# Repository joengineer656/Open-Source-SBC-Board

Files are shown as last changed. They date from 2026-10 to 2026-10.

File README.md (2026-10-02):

# Open-Source-SBC-Board

A custom single-board computer built around the Rockchip RK3576 SoC, designed as a learning project to explore modern SBC architecture.

> **Status: Work in Progress — v2 current.** Schematic in progress. Not yet fabricated. V2 schematics are not final – expect minor errors.

## Which version are you looking at?

**You are viewing `v2` (default, `main` branch).**

- **Want v1 (old)?** 
  - Switch branch: `archive/v1` in the GitHub branch dropdown, or
  - Download ZIP: [Releases → v1.0](https://github.com/joengineer656/Open-Source-SBC-Board/releases/tag/v1.0)
  - Clone specific: `git clone -b archive/v1 https://github.com/joengineer656/Open-Source-SBC-Board.git`
- **Want v2?** You're here. Or [Releases → v2.0](https://github.com/joengineer656/Open-Source-SBC-Board/releases/tag/v2.0) for ZIP.

| Version | Branch | Tag | Status |
|---|---|-----|---|
| v2 (this page) | `main` | `v2.0` | active development, default view |
| v1 (archived) | `archive/v1` | `v1.0` | frozen, read-only |

## Overview

This board is a learning project exploring the design of a modern, feature-rich SBC. It combines a high-performance RK3576 application processor with an RP2350A companion MCU for IO offloading, targeting a balance between compute power and real-time IO capability.

V2 is a cleaned-up / upgraded version of the V1 design (ref: [devmeb0/RK3576-SBC](https://github.com/devmeb0/RK3576-SBC)). Main V2 deltas: **second Gigabit Ethernet port, M.2 Key-E socket for wireless modules (no FCC cert needed for the base board), onboard CR2032 RTC backup battery (not external), schematic cleanup + notes throughout.**

## Key Specifications (v2)

| Feature | Specification |
|---|---|
| **SoC** | Rockchip RK3576 – 4x Cortex-A72 @ 2.2GHz + 4x Cortex-A53 @ 1.8GHz, Mali-G52 MC3, 6 TOPS NPU |
| **Companion MCU** | Raspberry Pi RP2350A (IO co-processor, USB-C, SWD/JTAG) |
| **RAM** | 32-bit LPDDR5 (Micron MT62F1G32D4DR-031) |
| **Storage** | UFS 2.0, eMMC 5.1 modular, µSD card, SPI flash (W25Q128 for MCU) |
| **Video Output** | HDMI 2.1 / eDP 1.3, USB-C DP1.4 Alt-Mode, 4-lane MIPI DSI + 0.96" OLED header |
| **Camera** | MIPI CSI 4-lane (or split 2+2) |
| **Networking** | Dual Gigabit Ethernet (2x RTL8211F, PoE optional), M.2 Key-E 67-pin for WiFi/BT |
| **USB** | 4x USB 3.2 Host (RTS5411 hub), 1x USB-C OTG/PD (FUSB302), 1x USB-C for MCU |
| **Expansion** | 40-pin RPi-compatible header, PCIe 2.1 x1 + SATA3 via FPC |
| **Display** | 0.96" OLED header (8-pin) |
| **RTC** | RV-3028-C7 + FRAM, onboard CR2032 holder (BAT-HLD-001) |
| **PMIC** | RK806S-5 + SY8388 / SY8089 DC/DCs |
| **Power In** | Barrel jack, USB-C 5V, USB-C PD, PoE option, 40-pin header |

## Features (v2)

**1. SoC – Rockchip RK3576 (FCCSP698)**
Octa-core big.LITTLE, Cortex-M0 for user code, Mali-G52 MC3 (OpenGL ES 3.2 / Vulkan 1.2 / OpenCL 2.1), 6 TOPS NPU (INT4/8/16, FP16/BF16/TF32), 16MP ISP with HDR/3DNR, 8K@30 / 4K@120 decode, 4K@60 encode. 2x RGMII, PCIe2.1/SATA3/USB3 combo lanes, 2x CAN-FD on-chip. OS: Linux / Android 14 / Yocto / Buildroot.

**2. Memory – 32-bit LPDDR5**
`LPDDR5.kicad_sch`: Micron MT62F1G32D4DR-031, 32-bit dual-channel layout per RK3576 reference.

**3. Storage – eMMC + UFS + microSD + SPI**
- `eMMC/UFS.kicad_sch` + `UFS/eMMC.kicad_sch`: eMMC 5.1 modular footprint + UFS 2.0 HS-G3.
- `uSD_Card.kicad_sch`: push-push microSD with AP2553 load-switch power + TPD4E ESD.
- `RP2350A.kicad_sch`: 2x W25Q128JVS SPI flash for the co-MCU.

**4. Display – 3x concurrent**
- `HDMI.kicad_sch`: HDMI 2.1 / eDP 1.3 combo, TPD4E05U06 ESD, TXB0104 translators, AP2553 5V switch.
- `USBC_SOC.kicad_sch`: USB-C Alt-Mode DP1.4 + USB3 combo, FUSB302 PD controller, TPS22953 switches.
- `MIPI.kicad_sch`: 4-lane MIPI DSI TX via 30-pin FPC, TXS0108 level-shifted.
- `oled_screen.kicad_sch`: 0.96" OLED 8-pin header for status/debug.

**5. Network – Dual GbE + M.2 Key-E (V2 highlight)**
- `Ethernet.kicad_sch`: 2x RTL8211F-CG PHYs (U25/U26, 2x 25 MHz crystals), LPJG0926HENL magjacks, PoE input headers (PoE optional).
- `Wireless.kicad_sch`: M.2 Key-E 67-pin socket APCI0108-P001A (LCSC C7498141), 0.5 mm right-angle, for off-the-shelf WiFi/BT modules – replaces soldered wireless, so the base board itself needs no FCC certification.

**6. USB**
- `USBA_Host.kicad_sch`: 4x USB3.2 Host via 2x RTS5411S-GR hubs, SY6280 current-limit per port, TPD4E ESD.
- `USBC_SOC.kicad_sch`: 1x USB-C OTG/Host Alt-Mode with PD negotiation – can also be power input.
- `RP2350A.kicad_sch`: separate USB-C 2.0 16P for the MCU.

**7. Camera**
`MIPI.kicad_sch`: MIPI CSI RX – 4-lane or split 2+2. Feeds RK3576 triple CSI + 16MP ISP.

**8. Power – RK806S-5 + discretes**
`Power.kicad_sch`: RK806S-5 PMIC, 2x SY8388ARHC + SY8089AAAC DC/DCs, AO3401 FETs, SMBJ TVS. Inputs: barrel-jack, USB-C 5V/3A-5A with UVLO/OVLO, USB-C PD in, PoE option, or 40-pin header 5V.

**9. RTC – onboard battery (V2 change)**
`RTC.kicad_sch`: RV-3028-C7 RTC + FM24C64/M24C64 FRAM/EEPROM, AO3401 OR-ing, fuse + SMBJ. CR2032 coin holder Linx BAT-HLD-001 **on-board** – V1 used an external JST battery.

**10. Expansion**
- `PCIe.kicad_sch` + `connectors.kicad_sch`: PCIe 2.1 x1 + SATA3 via TE 1-2199230-5 FPCs.
- `40pin_GPIO.kicad_sch`: Raspberry-Pi-compatible 40-pin header, 3x AP2553 load switches, SMBJ ESD: 28x GPIO / 13x PWM, 5x UART, 5x I2C, 1x I3C, 2x SPI, CAN, PDM, SDIO, 12-bit SAR-ADC 1MS/s, 3.3V out / 5V in-out.

**11. Co-MCU – RP2350A**
`RP2350A.kicad_sch`: RP2350A with ETA7014 regulators, W25Q128 flash, USB-C, SWD/JTAG header, tactile buttons. For real-time IO / housekeeping offload.

**12. Bring-up / mechanical**
`Fixtures.kicad_sch`: mounting holes, fiducials, test-point probes, UART/SWD debug header, boot DIP, maskrom + power tactiles, dual power/activity LEDs, active fan header.

## Architecture

```
┌─────────────────────────────────────────────────────┐
│                    RK3576 SoC                        │
│  ┌──────────┐  ┌──────────┐  ┌──────────────────┐  │
│  │  CPU     │  │  GPU     │  │  Memory Ctrl     │  │
│  │  (ARM)   │  │          │  │  (LPDDR5)        │  │
│  └──────────┘  ──────────┘  └──────────────────  │
│  ┌──────────  ┌──────────┐  ┌──────────────────┐  │
│  │  PCIe    │  │  USB 3.2 │  │  MIPI CSI/DSI    │  │
│  └──────────  └──────────┘  └──────────────────┘  │
│  ┌──────────┐  ┌──────────┐  ┌──────────────────┐  │
│  │  HDMI    │  │  Ethernet│  │  UFS/eMMC/SD     │  │
│  └──────────┘  └──────────┘  └──────────────────┘  │
└─────────────────────────────────────────────────────┘
         │                    │
         │ SPI/I2C/UART       │ USB
         ▼                    ▼
─────────────────┐   ┌─────────────────┐
│   RP2350A MCU   │   │   USB Hub       │
│  (IO offload)   │   │  (Host ports)   │
└─────────────────┘   └─────────────────┘
         │
         ▼
┌─────────────────┐
│  40-pin Header  │
│  (RPi compat)   │
└─────────────────┘
```

## Open in KiCad

Project file: `RK3576 SBCv2.kicad_pro` (KiCad 10.0)
Top sheet: `block_diagrame.kicad_sch` → `RK3576.kicad_sch` (SOC) + peripherals.

## Schematic Sheets (v2)

| Sheet | Description |
|---|---|
| `block_diagrame.kicad_sch` | Top-level block diagram |
| `RK3576.kicad_sch` | RK3576 SoC, decoupling, strapping |
| `RP2350A.kicad_sch` | RP2350A companion MCU, USB-C, SWD |
| `Power.kicad_sch` | RK806S-5 PMIC and power distribution |
| `LPDDR5.kicad_sch` | LPDDR5 memory (Micron MT62F) |
| `Ethernet.kicad_sch` | Dual Gigabit Ethernet (2x RTL8211F, PoE) |
| `Wireless.kicad_sch` | M.2 Key-E 67-pin WiFi/BT socket |
| `HDMI.kicad_sch` | HDMI 2.1 output |
| `MIPI.kicad_sch` | MIPI DSI/CSI via FPC |
| `PCIe.kicad_sch` | PCIe 2.1 / SATA via FPC |
| `USBA_Host.kicad_sch` | 4x USB-A host (RTS5411 hub) |
| `USBC_SOC.kicad_sch` | USB-C to SoC, PD (FUSB302) |
| `uSD_Card.kicad_sch` | µSD card slot |
| `eMMC/UFS.kicad_sch` + `UFS/eMMC.kicad_sch` | eMMC / UFS storage |
| `RTC.kicad_sch` | RV-3028 RTC + onboard CR2032 |
| `oled_screen.kicad_sch` | 0.96" OLED header |
| `40pin_GPIO.kicad_sch` | RPi-compatible header |
| `connectors.kicad_sch`, `dc_power_soket.kicad_sch` | Power / debug connectors |
| `Fixtures.kicad_sch` | Test points, fiducials |
| `directive_labels.kicad_sch` | Netclass directives |

> Note: `eMMC/UFS.kicad_sch` and `UFS/eMMC.kicad_sch` names are swapped upstream — kept as-is to avoid breaking sheet references. Excluded from repo (per `.gitignore`): `.history/`, `Resources/`, `*.bak`, `*.lck`, `project.kicad_dru`, `.hs_rules.json`, lowercase dup placeholders (`fixtures`/`power`), empty orphans (`digital`, `mechanical`, `output`, `USBC_MCU`, `eMMC_UFS`).

## Repository Structure (v2 on `main`)

```
Open-Source-SBC-Board/ (main = v2)
├── RK3576 SBCv2.kicad_pro       # KiCad project file
├── RK3576 SBCv2.kicad_sch       # Project root sheet
├── RK3576 SBCv2.kicad_pcb       # PCB layout (in progress)
├── RK3576 SBCv2.kicad_prl
├── RK3576 SBCv2.kicad_dru
├── *.kicad_sch                  # Hierarchical schematic sheets
├── eMMC/ UFS/                   # Storage sheets
├── LICENSE                      # CERN-OHL-P v2
├── README.md                     # This file
└── .gitignore                    # KiCad ignores (*.bak, .lck, .history/)
```

v1 lives only on branch `archive/v1` + tag `v1.0`, not in this tree.

## Design Goals

1. **Learn modern SBC design** — power delivery, high-speed interfaces (LPDDR5, UFS, PCIe, USB 3.2), mixed-signal layout
2. **Real-time IO capability** — RP2350A handles time-critical tasks independently of the Linux-running SoC
3. **Rich connectivity** — Dual Ethernet, M.2 Key-E WiFi/BT, USB, PCIe, MIPI, HDMI in a compact form factor
4. **Open source** — full schematic and PCB released under CERN-OHL-P

## For maintainers: how versions are stored

```bash
# v1 frozen
git branch archive/v1   # from old main
git tag v1.0 archive/v1

# v2 is main
git tag v2.0 main

# push all (needs auth)
git push origin archive/v1 v1.0 main v2.0
gh release create v1.0 --target archive/v1 --title "v1.0 - archived" --notes "Frozen v1. See branch archive/v1."
gh release create v2.0 --target main --title "v2.0 - current" --notes "Current v2. Default branch main."
```

Users get v2 by default, v1 via branch dropdown or Releases ZIP — i.e. “2 repos in 1 repo”.

## License

This hardware design is licensed under the **CERN Open Hardware Licence Version 2 — Permissive** (CERN-OHL-P v2).

See [LICENSE](LICENSE) for the full text.

## Acknowledgments

- [Rockchip](https://www.rock-chips.com/) for the RK3576 SoC
- [Raspberry Pi](https://www.raspberrypi.com/) for the RP2350A
- [KiCad](https://www.kicad.org/) for the EDA tools
- [CERN](https://ohwr.org/project/cernohl/) for the OHL license
- [devmeb0/RK3576-SBC](https://github.com/devmeb0/RK3576-SBC) V1 reference design

---

*This is a learning project. The design has not been fabricated or tested yet. Use at your own risk.*

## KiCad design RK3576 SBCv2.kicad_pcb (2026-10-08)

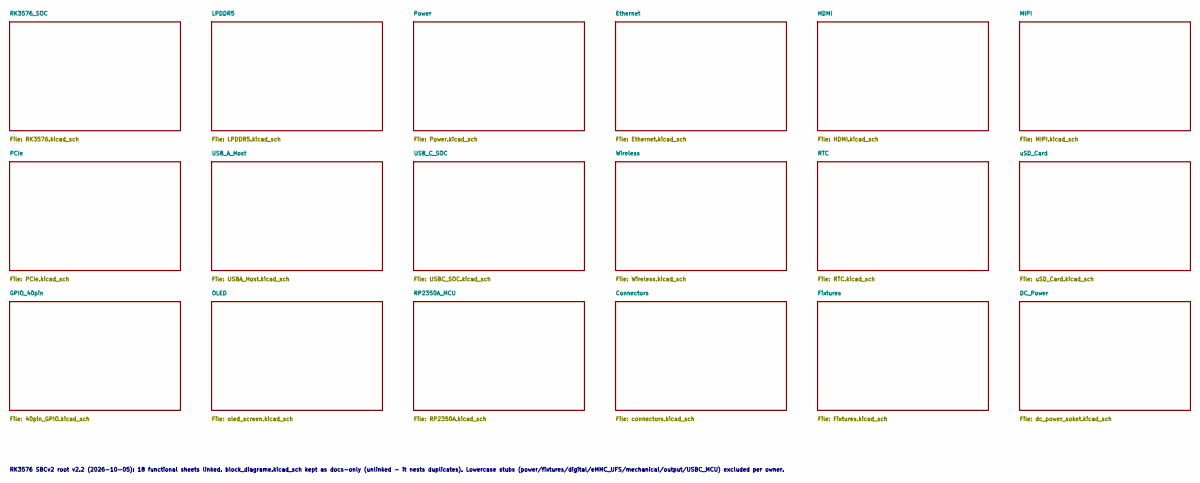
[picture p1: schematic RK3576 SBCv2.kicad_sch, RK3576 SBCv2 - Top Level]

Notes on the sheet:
RK3576 SBCv2 root v2.2 (2026-10-05): 18 functional sheets linked. block_diagrame.kicad_sch kept as docs-only (unlinked - it nests duplicates). Lowercase stubs (power/fixtures/digital/eMMC_UFS/mechanical/output/USBC_MCU) excluded per owner.

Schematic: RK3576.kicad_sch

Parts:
C1, C10: 12pF; C_0402_1005Metric; Mouser Part 187-CL05C120JB5NNNC; LCSC Part C26406
C2, C3, C4, C5, C6, C48, C49, C50, C106, C107, C108, C109, C110, C111: 22u; C_0603_1608Metric; Mouser Part CL10A226MP8NUNE; LCSC Part C86295
C7, C8, C9, C11, C13, C14, C15, C16, C18, C19, C20, C21, C22, C23, C28, C35, C36, C37, C38, C39, C40, C42, C47, C51, C53, C54, C55, C56, C57, C59, C60, C61, C62, C63, C64, C65, C66, C67, C68, C69, C70, C71, C72, C73, C74, C75, C76, C77, C78, C79, C80, C81, C82, C83, C84, C85, C86, C87, C88, C89, C90, C91, C92, C93, C94, C95, C96, C97, C98, C99, C100, C101, C102, C103, C104: 1u; C_0201_0603Metric_Pad0.64x0.40mm_HandSolder; Mouser Part CL03A105KP3NSNC; LCSC Part C5209398
C12, C17, C41, C43, C44, C45, C46, C52, C58: 10u; C_0603_1608Metric; Mouser Part 187-CL10A106KP8NNNC; LCSC Part C19702
C24, C25, C26, C27, C29, C30, C31, C32, C33, C34: 100n; C_0201_0603Metric_Pad0.64x0.40mm_HandSolder; Mouser Part 187-CL03A104KO3NNND; LCSC Part C307380
C105, C112: 18pF; C_0402_1005Metric; Mouser Part 603-CC402FRNPO9BN180; LCSC Part C541431
D1, D2: PESD5V0S1BA; D_SOD-323_TVS; Mouser Part 771-PESD5V0S1BA-T/R; LCSC Part C5158048
D3: SMBJ5.0CA; D_SMB_TVS; Mouser Part 581-SMBJ5.0CA; LCSC Part C113975
J1: B4B Connector; FanPinHeader_1x04_P2.54mm_Vertical; Mouser Part 306-B4BXHALFSN; LCSC Part C144395
LED1, LED2: XL-1608SURC-06; LED_0603_1608Metric; LCSC Part C965799
Q1: 2SK3018; SOT-323_SC-70; LCSC Part C20069148
R1: 4.7k; R_0402_1005Metric; Mouser Part 603-RC0402FR-074K7L; LCSC Part C105871; not fitted
R2, R30, R31, R32, R34: 22R; R_0402_1005Metric; Mouser Part 603-RC0402FR-070RL; LCSC Part C106231
R3, R5, R6, R26, R28: 4.7k; R_0402_1005Metric; Mouser Part 603-RC0402FR-074K7L; LCSC Part C105871
R4, R33: 510k; R_0402_1005Metric; Mouser Part 603-RC0402FR-07510KL; LCSC Part C137961
R7, R233: 0R; R_0402_1005Metric; Mouser Part 603-RC0402FR-070RL; LCSC Part C106231
R8, R9: 100R; R_0402_1005Metric; Mouser Part 603-RC0402FR-0722RL; LCSC Part C114765
R10, R18, R19, R20, R21, R22, R23: 10k; R_0402_1005Metric; Mouser Part 603-RC0402FR-0710KL; LCSC Part C60490
R11, R13, R14: 1k; R_0402_1005Metric; Mouser Part 603-RC0402FR-071KL; LCSC Part C106235
R12: 100k; R_0402_1005Metric; Mouser Part 603-RC0402FR-0710KL; LCSC Part C60490
R15: 6.8k; R_0402_1005Metric; Mouser Part 603-RC0402FR-076K8L; LCSC Part C93940
R16: 23.2k; R_0402_1005Metric; Mouser Part 603-AC0402FR-0723K2L; LCSC Part C226362
R17: 88.7k; R_0402_1005Metric; Mouser Part 603-RC0402FR-0788K7L; LCSC Part C477808
R24, R25, R35: 8.2k; R_0402_1005Metric; Mouser Part 603-RT0402FRE078K2L; LCSC Part C136971
R27, R29: 200R; R_0402_1005Metric; Mouser Part 603-RT0402FRE07200RL; LCSC Part C854192
SW1: DSHP03TS-S; SW_DIP_SPSTx03_Slide_KingTek_DSHP03TJ_W5.25mm_P1.27mm_JPin; LCSC Part C319051
SW2: XUNPU TS-1089S-02526; LCSC Part C455282
U1: RK3576; FCCSP-698_L17.2-W16.1-TL_RK3576; MPN RK3576; LCSC Part C42388007
Y1: TXM24M0004322FBCDO00T; Crystal_SMD_3225-4Pin_3.2x2.5mm; LCSC Part C362340
Y2: XTM32026000FT00351001; Crystal_SMD_3225-4Pin_3.2x2.5mm; LCSC Part C37635380

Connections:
/40pin GPIO/I2C8_SCL_M3_RTC_EEPROM: U1.A11 (I2C8_SCL_M3); also elsewhere on the board
/40pin GPIO/I2C8_SDA_M3_RTC_EEPROM: U1.A13 (I2C8_SDA_M3); also elsewhere on the board
/40pin GPIO/SPI1_{MCU}.CS: R6.2, U1.1E7 (GPIO3_D7_d); also elsewhere on the board
/40pin GPIO/SPI1_{MCU}.SCK: R1.2, U1.1E12 (SPI3_CLK_M1); also elsewhere on the board
/40pin GPIO/SPI1_{MCU}.SDI: R5.2, U1.1C10 (SPI3_MOSI_M1); also elsewhere on the board
/40pin GPIO/SPI1_{MCU}.SDO: R3.2, U1.1D10 (SPI3_MISO_M1); also elsewhere on the board
/Ethernet/ETH0_{PHY}.MDC: U1.1B13 (ETH1_MDC_M0); also elsewhere on the board
/Ethernet/ETH0_{PHY}.MDIO: U1.1B15 (ETH1_MDIO_M0); also elsewhere on the board
/Ethernet/ETH0_{PHY}.RXC: U1.1C18 (ETH0_RXCLK_M1); also elsewhere on the board
/Ethernet/ETH0_{PHY}.RXCTL: U1.1A20 (ETH0_RXCTL_M1); also elsewhere on the board
/Ethernet/ETH0_{PHY}.RXD0: U1.B22 (ETH0_RXD0_M1); also elsewhere on the board
/Ethernet/ETH0_{PHY}.RXD1: U1.1A19 (ETH0_RXD1_M1); also elsewhere on the board
/Ethernet/ETH0_{PHY}.RXD2: U1.B21 (ETH0_RXD2_M1); also elsewhere on the board
/Ethernet/ETH0_{PHY}.RXD3: U1.A21 (ETH0_RXD3_M1); also elsewhere on the board
/Ethernet/ETH0_{PHY}.TXC: U1.1B16 (ETH0_TXCLK_M1); also elsewhere on the board
/Ethernet/ETH0_{PHY}.TXCTL: U1.B20 (ETH0_TXCTL_M1); also elsewhere on the board
/Ethernet/ETH0_{PHY}.TXD0: U1.1A18 (ETH0_TXD0_M1); also elsewhere on the board
/Ethernet/ETH0_{PHY}.TXD1: U1.B19 (ETH0_TXD1_M1); also elsewhere on the board
/Ethernet/ETH0_{PHY}.TXD2: U1.A19 (ETH0_TXD2_M1); also elsewhere on the board
/Ethernet/ETH0_{PHY}.TXD3: U1.1A17 (ETH0_TXD3_M1); also elsewhere on the board
/Ethernet/ETH0_{PHY}_CLK_{OUT}: U1.1E15 (ETH_CLK0_25M_OUT_M1); also elsewhere on the board
/Ethernet/ETH0_{PHY}_INT: U1.1C6 (GPIO4_A3_d); also elsewhere on the board
/Ethernet/ETH0_{PHY}_nRST: U1.1D6 (GPIO4_A2_d); also elsewhere on the board
/Ethernet/ETH1_{PHY}.MDC: U1.1B18 (ETH0_MDC_M1); also elsewhere on the board
/Ethernet/ETH1_{PHY}.MDIO: U1.1D16 (ETH0_MDIO_M1); also elsewhere on the board
/Ethernet/ETH1_{PHY}.RXC: U1.1D15 (ETH1_RXCLK_M0); also elsewhere on the board
/Ethernet/ETH1_{PHY}.RXCTL: U1.B18 (ETH1_RXCTL_M0); also elsewhere on the board
/Ethernet/ETH1_{PHY}.RXD0: U1.1A16 (ETH1_RXD0_M0); also elsewhere on the board
/Ethernet/ETH1_{PHY}.RXD1: U1.B17 (ETH1_RXD1_M0); also elsewhere on the board
/Ethernet/ETH1_{PHY}.RXD2: U1.A17 (ETH1_RXD2_M0); also elsewhere on the board
/Ethernet/ETH1_{PHY}.RXD3: U1.1A15 (ETH1_RXD3_M0); also elsewhere on the board
/Ethernet/ETH1_{PHY}.TXC: U1.1C15 (ETH1_TXCLK_M0); also elsewhere on the board
/Ethernet/ETH1_{PHY}.TXCTL: U1.B16 (ETH1_TXCTL_M0); also elsewhere on the board
/Ethernet/ETH1_{PHY}.TXD0: U1.1A14 (ETH1_TXD0_M0); also elsewhere on the board
/Ethernet/ETH1_{PHY}.TXD1: U1.B15 (ETH1_TXD1_M0); also elsewhere on the board
/Ethernet/ETH1_{PHY}.TXD2: U1.A15 (ETH1_TXD2_M0); also elsewhere on the board
/Ethernet/ETH1_{PHY}.TXD3: U1.1A13 (ETH1_TXD3_M0); also elsewhere on the board
/Ethernet/ETH1_{PHY}_CLK_{OUT}: U1.1D18 (ETH_CLK1_25M_OUT_M0); also elsewhere on the board
/Ethernet/ETH1_{PHY}_INT: U1.1B6 (GPIO4_A5_d); also elsewhere on the board
/Ethernet/ETH1_{PHY}_nRST: U1.1C5 (GPIO4_A4_d); also elsewhere on the board
/HDMI/HDMI_PWREN_H: U1.AK1 (GPIO4_C5_d); also elsewhere on the board
/HDMI/HDMI_TX_CEC_M0: U1.AK3 (HDMI_TX_CEC_M0); also elsewhere on the board
/HDMI/HDMI_TX_HPDIN_M0: U1.AK2 (HDMI_TX_HPDIN_M0); also elsewhere on the board
/HDMI/HDMI_TX_ON: U1.AL3 (GPIO4_C4_d); also elsewhere on the board
/HDMI/HDMI_TX_SCL: U1.AL2 (HDMI_TX_SCL); also elsewhere on the board
/HDMI/HDMI_TX_SDA: U1.1AE2 (HDMI_TX_SDA); also elsewhere on the board
/LPDDR5/LPDDR5_A.CA0: U1.T1 (LP5_A0_A); also elsewhere on the board
/LPDDR5/LPDDR5_A.CA1: U1.1N1 (LP5_A1_A); also elsewhere on the board
/LPDDR5/LPDDR5_A.CA2: U1.1R3 (LP5_A2_A); also elsewhere on the board
/LPDDR5/LPDDR5_A.CA3: U1.1T2 (LP5_A3_A); also elsewhere on the board
/LPDDR5/LPDDR5_A.CA4: U1.1M5 (LP5_A4_A); also elsewhere on the board
/LPDDR5/LPDDR5_A.CA5: U1.1P5 (LP5_A5_A); also elsewhere on the board
/LPDDR5/LPDDR5_A.CA6: U1.1R5 (LP5_A6_A); also elsewhere on the board
/LPDDR5/LPDDR5_A.CK_N: U1.P1 (LP5_CLKN_A); also elsewhere on the board
/LPDDR5/LPDDR5_A.CK_P: U1.1L1 (LP5_CLKP_A); also elsewhere on the board
/LPDDR5/LPDDR5_A.CS0: U1.1N3 (LP5_CSN0_A); also elsewhere on the board
/LPDDR5/LPDDR5_A.CS1: U1.1N5 (LP5_CSN1_A); also elsewhere on the board
/LPDDR5/LPDDR5_A.DMI0: U1.1V1 (LP5_DMI0_A); also elsewhere on the board
/LPDDR5/LPDDR5_A.DMI1: U1.AE1 (LP5_DMI1_A); also elsewhere on the board
/LPDDR5/LPDDR5_A.DQ0: U1.W1 (LP5_DQ0_A); also elsewhere on the board
/LPDDR5/LPDDR5_A.DQ1: U1.1T1 (LP5_DQ1_A); also elsewhere on the board
/LPDDR5/LPDDR5_A.DQ2: U1.1P1 (LP5_DQ2_A); also elsewhere on the board
/LPDDR5/LPDDR5_A.DQ3: U1.U1 (LP5_DQ3_A); also elsewhere on the board
/LPDDR5/LPDDR5_A.DQ4: U1.1V3 (LP5_DQ4_A); also elsewhere on the board
/LPDDR5/LPDDR5_A.DQ5: U1.1W4 (LP5_DQ5_A); also elsewhere on the board
/LPDDR5/LPDDR5_A.DQ6: U1.AC1 (LP5_DQ6_A); also elsewhere on the board
/LPDDR5/LPDDR5_A.DQ7: U1.AB1 (LP5_DQ7_A); also elsewhere on the board
/LPDDR5/LPDDR5_A.DQ8: U1.AF1 (LP5_DQ8_A); also elsewhere on the board
/LPDDR5/LPDDR5_A.DQ9: U1.1AB1 (LP5_DQ9_A); also elsewhere on the board
/LPDDR5/LPDDR5_A.DQ10: U1.1AD1 (LP5_DQ10_A); also elsewhere on the board
/LPDDR5/LPDDR5_A.DQ11: U1.AH1 (LP5_DQ11_A); also elsewhere on the board
/LPDDR5/LPDDR5_A.DQ12: U1.1Y1 (LP5_DQ12_A); also elsewhere on the board
/LPDDR5/LPDDR5_A.DQ13: U1.1W2 (LP5_DQ13_A); also elsewhere on the board
/LPDDR5/LPDDR5_A.DQ14: U1.1AA3 (LP5_DQ14_A); also elsewhere on the board
/LPDDR5/LPDDR5_A.DQ15: U1.1AA1 (LP5_DQ15_A); also elsewhere on the board
/LPDDR5/LPDDR5_A.RDQS0_N: U1.Y1 (LP5_RDQS0N_A); also elsewhere on the board
/LPDDR5/LPDDR5_A.RDQS0_P: U1.1U1 (LP5_RDQS0P_A); also elsewhere on the board
/LPDDR5/LPDDR5_A.RDQS1_N: U1.1AB3 (LP5_RDQS1N_A); also elsewhere on the board
/LPDDR5/LPDDR5_A.RDQS1_P: U1.1AB4 (LP5_RDQS1P_A); also elsewhere on the board
/LPDDR5/LPDDR5_A.WCK0_N: U1.1V4 (LP5_WCK0N_A); also elsewhere on the board
/LPDDR5/LPDDR5_A.WCK0_P: U1.1V5 (LP5_WCK0P_A); also elsewhere on the board
/LPDDR5/LPDDR5_A.WCK1_N: U1.1AA5 (LP5_WCK1N_A); also elsewhere on the board
/LPDDR5/LPDDR5_A.WCK1_P: U1.1AA6 (LP5_WCK1P_A); also elsewhere on the board
/LPDDR5/LPDDR5_B.CA0: U1.L1 (LP5_A0_B); also elsewhere on the board
/LPDDR5/LPDDR5_B.CA1: U1.1J1 (LP5_A1_B); also elsewhere on the board
/LPDDR5/LPDDR5_B.CA2: U1.1J3 (LP5_A2_B); also elsewhere on the board
/LPDDR5/LPDDR5_B.CA3: U1.1G2 (LP5_A3_B); also elsewhere on the board
/LPDDR5/LPDDR5_B.CA4: U1.1F4 (LP5_A4_B); also elsewhere on the board
/LPDDR5/LPDDR5_B.CA5: U1.1K5 (LP5_A5_B); also elsewhere on the board
/LPDDR5/LPDDR5_B.CA6: U1.1H5 (LP5_A6_B); also elsewhere on the board
/LPDDR5/LPDDR5_B.CK_N: U1.N1 (LP5_CLKN_B); also elsewhere on the board
/LPDDR5/LPDDR5_B.CK_P: U1.1K1 (LP5_CLKP_B); also elsewhere on the board
/LPDDR5/LPDDR5_B.CS0: U1.1K2 (LP5_CSN0_B); also elsewhere on the board
/LPDDR5/LPDDR5_B.CS1: U1.1M3 (LP5_CSN1_B); also elsewhere on the board
/LPDDR5/LPDDR5_B.DMI0: U1.B4 (LP5_DMI0_B); also elsewhere on the board
/LPDDR5/LPDDR5_B.DMI1: U1.1B1 (LP4_DMI1_B); also elsewhere on the board
/LPDDR5/LPDDR5_B.DQ0: U1.1D2 (LP5_DQ0_B); also elsewhere on the board
/LPDDR5/LPDDR5_B.DQ1: U1.1F2 (LP5_DQ1_B); also elsewhere on the board
/LPDDR5/LPDDR5_B.DQ2: U1.1G1 (LP5_DQ2_B); also elsewhere on the board
/LPDDR5/LPDDR5_B.DQ3: U1.K1 (LP5_DQ3_B); also elsewhere on the board
/LPDDR5/LPDDR5_B.DQ4: U1.1C3 (LP5_DQ4_B); also elsewhere on the board
/LPDDR5/LPDDR5_B.DQ5: U1.1B3 (LP5_DQ5_B); also elsewhere on the board
/LPDDR5/LPDDR5_B.DQ6: U1.A5 (LP5_DQ6_B); also elsewhere on the board
/LPDDR5/LPDDR5_B.DQ7: U1.G1 (LP5_DQ7_B); also elsewhere on the board
/LPDDR5/LPDDR5_B.DQ8: U1.1A1 (LP5_DQ8_B); also elsewhere on the board
/LPDDR5/LPDDR5_B.DQ9: U1.B1 (LP5_DQ9_B); also elsewhere on the board
/LPDDR5/LPDDR5_B.DQ10: U1.B2 (LP5_DQ10_B); also elsewhere on the board
/LPDDR5/LPDDR5_B.DQ11: U1.A2 (LP5_DQ11_B); also elsewhere on the board
/LPDDR5/LPDDR5_B.DQ12: U1.1E1 (LP5_DQ12_B); also elsewhere on the board
/LPDDR5/LPDDR5_B.DQ13: U1.1C1 (LP5_DQ13_B); also elsewhere on the board
/LPDDR5/LPDDR5_B.DQ14: U1.E1 (LP5_DQ14_B); also elsewhere on the board
/LPDDR5/LPDDR5_B.DQ15: U1.D1 (LP5_DQ15_B); also elsewhere on the board
/LPDDR5/LPDDR5_B.RDQS0_N: U1.1F1 (LP5_RDQS0N_B); also elsewhere on the board
/LPDDR5/LPDDR5_B.RDQS0_P: U1.H1 (LP5_RDQS0P_B); also elsewhere on the board
/LPDDR5/LPDDR5_B.RDQS1_N: U1.B3 (LP5_RDQS1N_B); also elsewhere on the board
/LPDDR5/LPDDR5_B.RDQS1_P: U1.A3 (LP5_RDQS1P_B); also elsewhere on the board
/LPDDR5/LPDDR5_B.WCK0_N: U1.1G4 (LP5_WCK0N_B); also elsewhere on the board
/LPDDR5/LPDDR5_B.WCK0_P: U1.1G5 (LP5_WCK0P_B); also elsewhere on the board
/LPDDR5/LPDDR5_B.WCK1_N: U1.1E4 (LP5_WCK1N_B); also elsewhere on the board
/LPDDR5/LPDDR5_B.WCK1_P: U1.1D4 (LP5_WCK1P_B); also elsewhere on the board
/LPDDR5/LPDDR5_nRTS: U1.1U5 (LP5_RESET); also elsewhere on the board
/MIPI/CAM1_CLK1_OUT_M0_1V8: U1.1C12 (GPIO3_D0_d); also elsewhere on the board
/MIPI/CAM1_CLK2_OUT_M0_1V8: U1.1A12 (GPIO3_D1_d); also elsewhere on the board
/MIPI/DSI0.TX_D2_P: U1.AL18 (MIPI_DPHY_DSI_TX_D2P); also elsewhere on the board
/MIPI/LCD_BL_PWM1_CH1_M0: U1.AD29 (PWM1_CH1_M0); also elsewhere on the board
/MIPI/LCD_PWREN_H: U1.1W23 (GPIO0_D0_d); also elsewhere on the board
/MIPI/MIPI_DPHY_CS2_CAM1_PDN_H: U1.1A10 (GPIO3_D2_d); also elsewhere on the board
/MIPI/MIPI_DPHY_CSI_CAM1_PDN_H: U1.1B7 (CAM_CLK2_OUT_M0); also elsewhere on the board
/MIPI/MIPI_DPHY_CSI_CAM2_RST_H: U1.1B12 (CAM_CLK1_OUT_M0); also elsewhere on the board
/PCIe/PCIE0.REFCLK_N: U1.1N23 (PCIE0_REFCLKN); also elsewhere on the board
/PCIe/PCIE0.REFCLK_P: U1.1N22 (PCIE0_REFCLKP); also elsewhere on the board
/PCIe/PCIE0.RX_N: U1.R29 (PCIE0_RXN); also elsewhere on the board
/PCIe/PCIE0.RX_P: U1.R28 (PCIE0_RXP); also elsewhere on the board
/PCIe/PCIE0.TX_N: U1.P28 (PCIE0_TXN); also elsewhere on the board
/PCIe/PCIE0.TX_P: U1.P29 (PCIE0_TXP); also elsewhere on the board
/PCIe/PCIE0_CLKREQ_L: U1.1A6 (SAI1_SDI0_M0); also elsewhere on the board
/PCIe/PCIE0_DET_L: U1.1A4 (SPDIF_TX0_M0); also elsewhere on the board
/PCIe/PCIE0_WAKE_L: U1.B8 (SPDIF_RX0_M0); also elsewhere on the board
/PCIe/PCIE0_nRST: U1.B6 (SAI1_SDO3_M0); also elsewhere on the board
/Power/I2C1_SCL_M0_RK806: U1.1T22 (I2C1_SCL_M0); also elsewhere on the board
/Power/I2C1_SDA_M0_RK806: U1.1T23 (I2C1_SDA_M0); also elsewhere on the board
/Power/PMIC_INT_L: U1.1T21 (PMIC_INT), U1.V29 (GPIO0_A0_d); also elsewhere on the board
/Power/PMIC_PWRON_L: U1.Y29 (GPIO0_A5_d); also elsewhere on the board
/Power/PMIC_PWR_CTRL1: U1.Y28 (PWR_CTRL1); also elsewhere on the board
/Power/PMIC_PWR_CTRL2: U1.1T24 (PWR_CTRL2); also elsewhere on the board
/Power/PMIC_nRST: R233.2; also elsewhere on the board
/RK3576 SOC/40GPIOs_GPIO(3_A6)_UART(1)_RX-M2: U1.1A7 (UART1_RX_M2)
/RK3576 SOC/40GPIOs_GPIO(3_A7)_UART(1)_TX-M2: U1.B13 (UART1_TX_M2)
/RK3576 SOC/40GPIOs_GPIO(3_B0)_UART(10)_RX-M0: U1.B14 (UART10_RX_M0)
/RK3576 SOC/40GPIOs_GPIO(3_B1)_UART(10)_TX-M0: U1.1A11 (UART10_TX_M0)
/RK3576 SOC/40GPIOs_GPIO(3_B4)_PWM(1)_CH4-M3: U1.B10 (PWM1_CH4_M3)
/RK3576 SOC/40GPIOs_GPIO(3_B5)_PWM(1)_CH5-M3: U1.1A9 (PWM1_CH5_M3)
/RK3576 SOC/40GPIOs_GPIO(3_B6)_PWM(0)_CH1-M3: U1.B11 (PWM0_CH1_M3)
/RK3576 SOC/40GPIOs_GPIO(3_B7)_UART(2)_RX-M2: U1.1D12 (UART2_RX_M2)
/RK3576 SOC/40GPIOs_GPIO(3_C0)_UART(2)_TX-M2: U1.1E9 (UART2_TX_M2)
/RK3576 SOC/40GPIOs_GPIO(3_C1)_I2C(5)_SDA-M3: U1.1B10 (I2C5_SDA_M3)
/RK3576 SOC/40GPIOs_GPIO(3_C2)_I2C(9)_SCL-M3: U1.B9 (I2C9_SCL_M3)
/RK3576 SOC/40GPIOs_GPIO(3_C3)_I2C(9)_SDA-M3: U1.1A8 (I2C9_SDA_M3)
/RK3576 SOC/40GPIOs_GPIO(3_C4)_I2C(5)_SCL-M3: U1.1D9 (I2C5_SCL_M3)
/RK3576 SOC/40GPIOs_GPIO(3_C5)_PWM(2)_CH2-M3: U1.1B9 (PWM2_CH2_M3)
/RK3576 SOC/40GPIOs_GPIO(3_C6): U1.1D7 (GPIO3_C6_d)
/RK3576 SOC/40GPIOs_GPIO(3_C7): U1.1C7 (GPIO3_C7_d)
/RK3576 SOC/BT_REG_ON_L: U1.1W21 (GPIO0_C3_d); also elsewhere on the board
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

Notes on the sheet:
ELECTROSTATIC-SENSITIVE DEVICE
HOT SURFACE
Notes
High Performance System
RK3576 MIPI (CSI/DCI)
Warnings
Power Source
SDIO 3.0 VDD_{IO5}
Internal DCDC Controls
VDD_{LDO}
VDD_{IO5}
VDD_{IO6}
Internal Systems
GPIOs 0-3
MIPI Physical
RK3576 USB2 (OTG/HUB)
Internal LDOs
RK3576 SARADC
1.65V ~ 3.6V
GPIOs 16-23
Fig. 2
VDD_{PSRAM0} VDD_{PSRAM1}
SARADC_VIN2_HW_ID: identifies the board revision SARADC_VIN5_BOM_ID: identifies the BOM That is not a security features it is a normal information
RK3576 (USB3 OTG/DP)
3.0V ~ 3.6V
2.97V ~ 3.63V
Internal Physical Layer
GPIOs 4-15
GPIOs 49-54
CSI0 for one High performance camera CSI1/2 for 2 cameras lower performance
Documentation Block
Fig. 1
VDD_{MIPI}
2.5V ~ 3.6V
VDD_{MIPI_DPHY}
GPIOs Group
RK3576 GPIO3 (40GPIO)
RK3576 HDMI
VDD_{IO0}
0.99V ~ 1.3V

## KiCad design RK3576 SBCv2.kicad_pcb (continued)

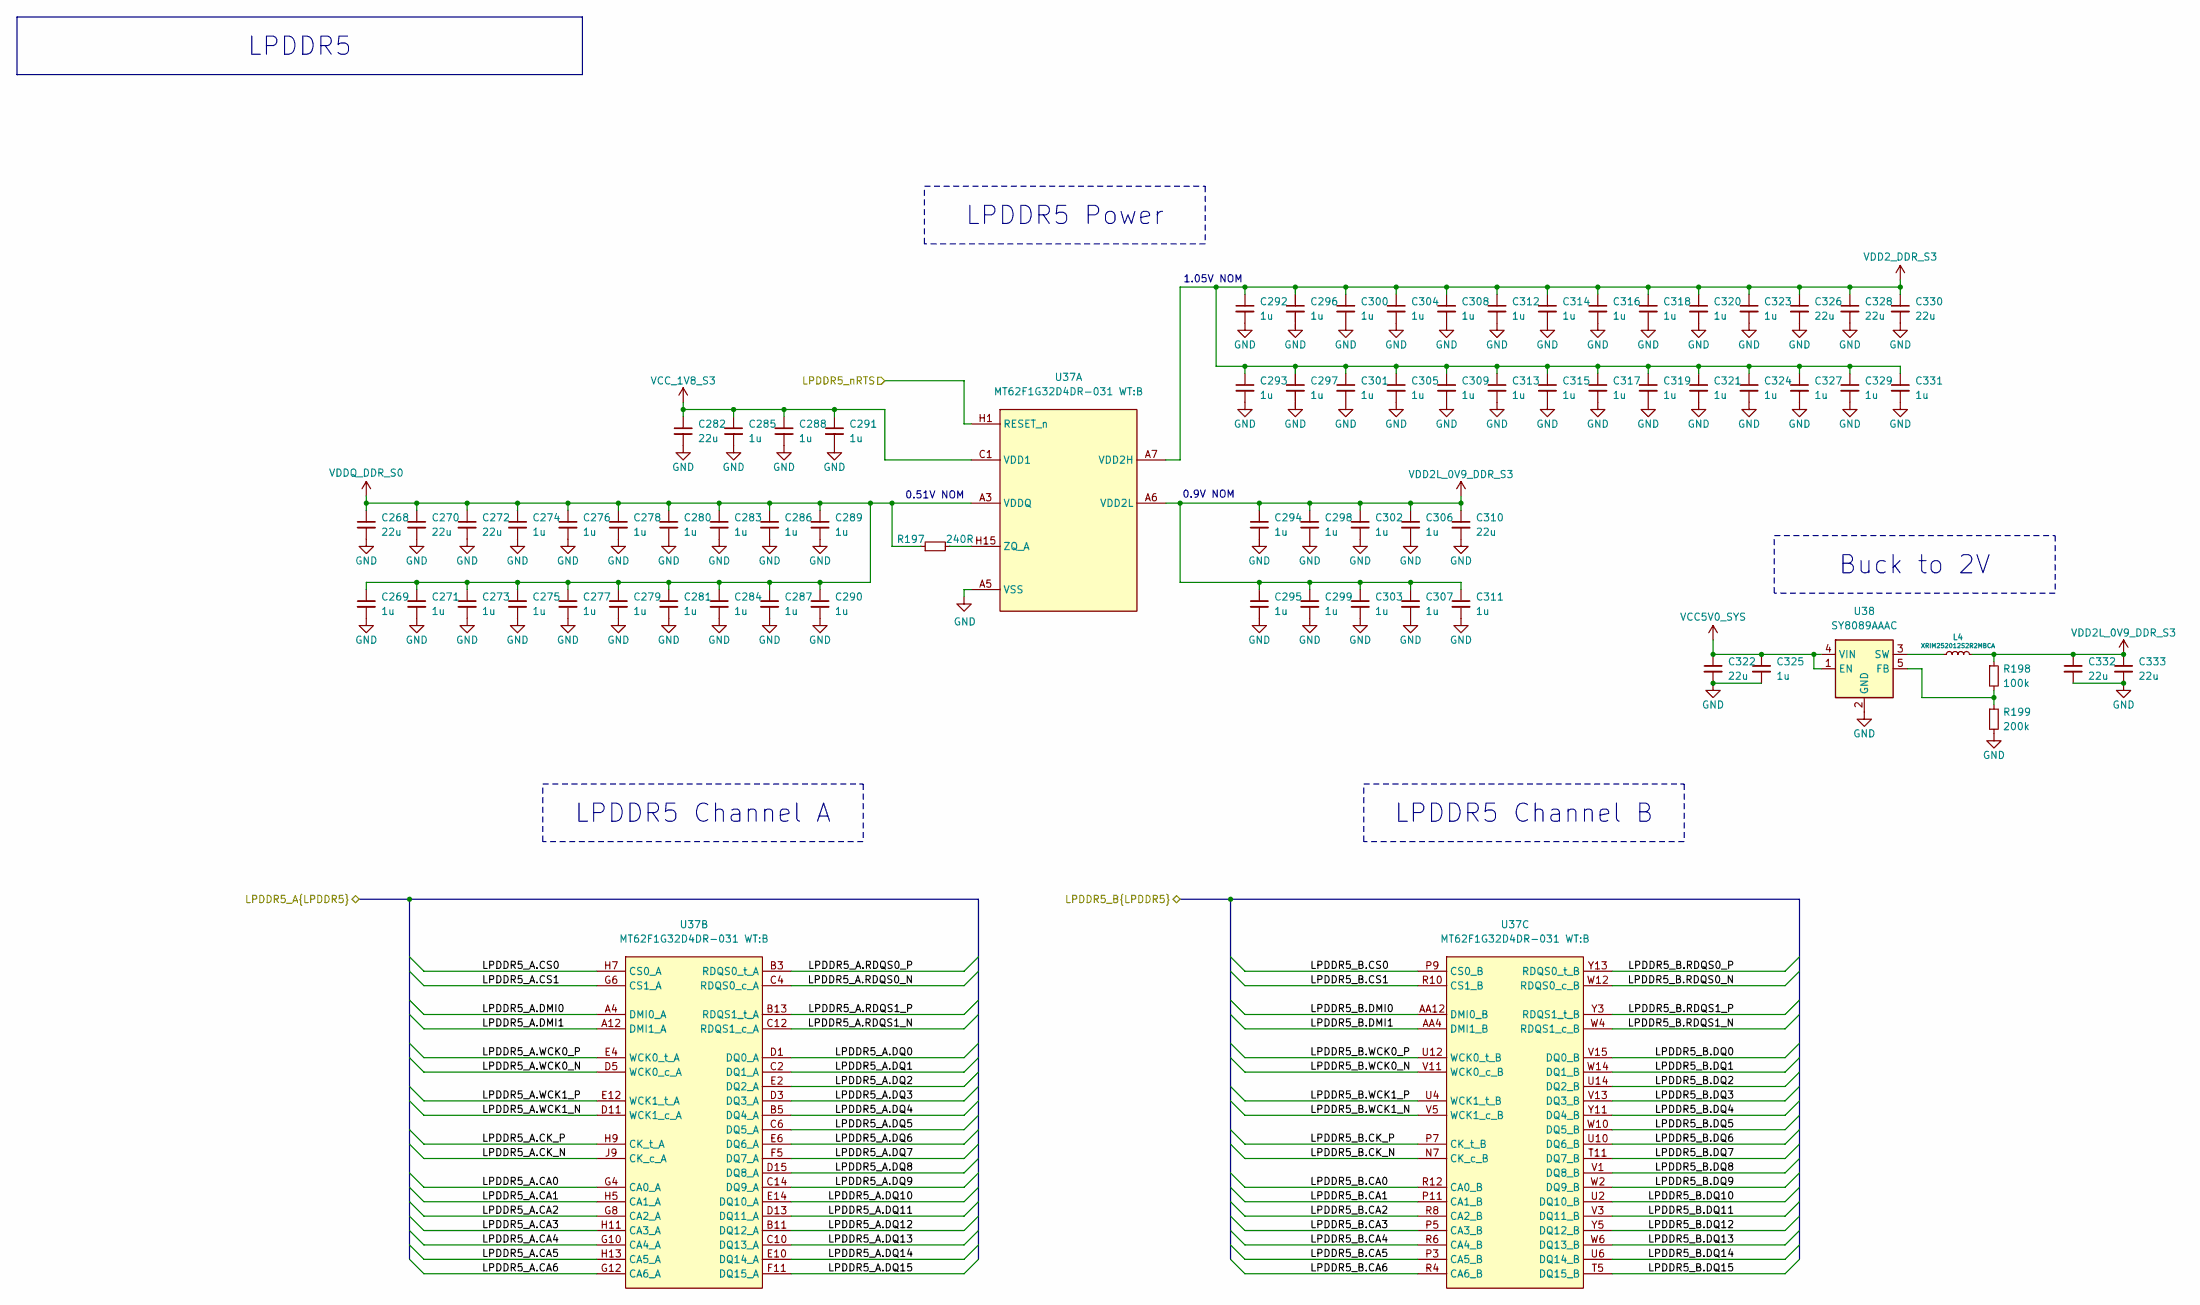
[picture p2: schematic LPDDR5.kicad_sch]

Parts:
C268, C270, C272, C282, C310, C322, C326, C328, C330, C332, C333: 22u; C_0603_1608Metric; Mouser Part CL10A226MP8NUNE; LCSC Part C86295
C269, C271, C273, C274, C275, C276, C277, C278, C279, C280, C281, C283, C284, C285, C286, C287, C288, C289, C290, C291, C292, C293, C294, C295, C296, C297, C298, C299, C300, C301, C302, C303, C304, C305, C306, C307, C308, C309, C311, C312, C313, C314, C315, C316, C317, C318, C319, C320, C321, C323, C324, C325, C327, C329, C331: 1u; C_0201_0603Metric_Pad0.64x0.40mm_HandSolder; Mouser Part CL03A105KP3NSNC; LCSC Part C5209398
L4: XRIM252012S2R2MBCA; L_1008_2520Metric; LCSC Part C22471111
R197: 240R; R_0402_1005Metric; Mouser Part 603-RC0402FR-07240RL; LCSC Part C114755
R198: 100k; R_0402_1005Metric; Mouser Part 603-RC0402FR-0710KL; LCSC Part C60490
R199: 200k; R_0402_1005Metric; Mouser Part 603-RC0402FR-0710KL; LCSC Part C60490
U37: MT62F1G32D4DR-031 WT:B; LPDDR5 BGA 315; MPN MT62F1G32D4DR-031 WT:B; Mouser Part 340-450481-TRAY
U38: SY8089AAAC; SOT-23-5; LCSC Part C78988

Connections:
/LPDDR5/LPDDR5_A.CA0: U37.G4 (CA0_A); also elsewhere on the board
/LPDDR5/LPDDR5_A.CA1: U37.H5 (CA1_A); also elsewhere on the board
/LPDDR5/LPDDR5_A.CA2: U37.G8 (CA2_A); also elsewhere on the board
/LPDDR5/LPDDR5_A.CA3: U37.H11 (CA3_A); also elsewhere on the board
/LPDDR5/LPDDR5_A.CA4: U37.G10 (CA4_A); also elsewhere on the board
/LPDDR5/LPDDR5_A.CA5: U37.H13 (CA5_A); also elsewhere on the board
/LPDDR5/LPDDR5_A.CA6: U37.G12 (CA6_A); also elsewhere on the board
/LPDDR5/LPDDR5_A.CK_N: U37.J9 (CK_c_A); also elsewhere on the board
/LPDDR5/LPDDR5_A.CK_P: U37.H9 (CK_t_A); also elsewhere on the board
/LPDDR5/LPDDR5_A.CS0: U37.H7 (CS0_A); also elsewhere on the board
/LPDDR5/LPDDR5_A.CS1: U37.G6 (CS1_A); also elsewhere on the board
/LPDDR5/LPDDR5_A.DMI0: U37.A4 (DMI0_A); also elsewhere on the board
/LPDDR5/LPDDR5_A.DMI1: U37.A12 (DMI1_A); also elsewhere on the board
/LPDDR5/LPDDR5_A.DQ0: U37.D1 (DQ0_A); also elsewhere on the board
/LPDDR5/LPDDR5_A.DQ1: U37.C2 (DQ1_A); also elsewhere on the board
/LPDDR5/LPDDR5_A.DQ2: U37.E2 (DQ2_A); also elsewhere on the board
/LPDDR5/LPDDR5_A.DQ3: U37.D3 (DQ3_A); also elsewhere on the board
/LPDDR5/LPDDR5_A.DQ4: U37.B5 (DQ4_A); also elsewhere on the board
/LPDDR5/LPDDR5_A.DQ5: U37.C6 (DQ5_A); also elsewhere on the board
/LPDDR5/LPDDR5_A.DQ6: U37.E6 (DQ6_A); also elsewhere on the board
/LPDDR5/LPDDR5_A.DQ7: U37.F5 (DQ7_A); also elsewhere on the board
/LPDDR5/LPDDR5_A.DQ8: U37.D15 (DQ8_A); also elsewhere on the board
/LPDDR5/LPDDR5_A.DQ9: U37.C14 (DQ9_A); also elsewhere on the board
/LPDDR5/LPDDR5_A.DQ10: U37.E14 (DQ10_A); also elsewhere on the board
/LPDDR5/LPDDR5_A.DQ11: U37.D13 (DQ11_A); also elsewhere on the board
/LPDDR5/LPDDR5_A.DQ12: U37.B11 (DQ12_A); also elsewhere on the board
/LPDDR5/LPDDR5_A.DQ13: U37.C10 (DQ13_A); also elsewhere on the board
/LPDDR5/LPDDR5_A.DQ14: U37.E10 (DQ14_A); also elsewhere on the board
/LPDDR5/LPDDR5_A.DQ15: U37.F11 (DQ15_A); also elsewhere on the board
/LPDDR5/LPDDR5_A.RDQS0_N: U37.C4 (RDQS0_c_A); also elsewhere on the board
/LPDDR5/LPDDR5_A.RDQS0_P: U37.B3 (RDQS0_t_A); also elsewhere on the board
/LPDDR5/LPDDR5_A.RDQS1_N: U37.C12 (RDQS1_c_A); also elsewhere on the board
/LPDDR5/LPDDR5_A.RDQS1_P: U37.B13 (RDQS1_t_A); also elsewhere on the board
/LPDDR5/LPDDR5_A.WCK0_N: U37.D5 (WCK0_c_A); also elsewhere on the board
/LPDDR5/LPDDR5_A.WCK0_P: U37.E4 (WCK0_t_A); also elsewhere on the board
/LPDDR5/LPDDR5_A.WCK1_N: U37.D11 (WCK1_c_A); also elsewhere on the board
/LPDDR5/LPDDR5_A.WCK1_P: U37.E12 (WCK1_t_A); also elsewhere on the board
/LPDDR5/LPDDR5_B.CA0: U37.R12 (CA0_B); also elsewhere on the board
/LPDDR5/LPDDR5_B.CA1: U37.P11 (CA1_B); also elsewhere on the board
/LPDDR5/LPDDR5_B.CA2: U37.R8 (CA2_B); also elsewhere on the board
/LPDDR5/LPDDR5_B.CA3: U37.P5 (CA3_B); also elsewhere on the board
/LPDDR5/LPDDR5_B.CA4: U37.R6 (CA4_B); also elsewhere on the board
/LPDDR5/LPDDR5_B.CA5: U37.P3 (CA5_B); also elsewhere on the board
/LPDDR5/LPDDR5_B.CA6: U37.R4 (CA6_B); also elsewhere on the board
/LPDDR5/LPDDR5_B.CK_N: U37.N7 (CK_c_B); also elsewhere on the board
/LPDDR5/LPDDR5_B.CK_P: U37.P7 (CK_t_B); also elsewhere on the board
/LPDDR5/LPDDR5_B.CS0: U37.P9 (CS0_B); also elsewhere on the board
/LPDDR5/LPDDR5_B.CS1: U37.R10 (CS1_B); also elsewhere on the board
/LPDDR5/LPDDR5_B.DMI0: U37.AA12 (DMI0_B); also elsewhere on the board
/LPDDR5/LPDDR5_B.DMI1: U37.AA4 (DMI1_B); also elsewhere on the board
/LPDDR5/LPDDR5_B.DQ0: U37.V15 (DQ0_B); also elsewhere on the board
/LPDDR5/LPDDR5_B.DQ1: U37.W14 (DQ1_B); also elsewhere on the board
/LPDDR5/LPDDR5_B.DQ2: U37.U14 (DQ2_B); also elsewhere on the board
/LPDDR5/LPDDR5_B.DQ3: U37.V13 (DQ3_B); also elsewhere on the board
/LPDDR5/LPDDR5_B.DQ4: U37.Y11 (DQ4_B); also elsewhere on the board
/LPDDR5/LPDDR5_B.DQ5: U37.W10 (DQ5_B); also elsewhere on the board
/LPDDR5/LPDDR5_B.DQ6: U37.U10 (DQ6_B); also elsewhere on the board
/LPDDR5/LPDDR5_B.DQ7: U37.T11 (DQ7_B); also elsewhere on the board
/LPDDR5/LPDDR5_B.DQ8: U37.V1 (DQ8_B); also elsewhere on the board
/LPDDR5/LPDDR5_B.DQ9: U37.W2 (DQ9_B); also elsewhere on the board
/LPDDR5/LPDDR5_B.DQ10: U37.U2 (DQ10_B); also elsewhere on the board
/LPDDR5/LPDDR5_B.DQ11: U37.V3 (DQ11_B); also elsewhere on the board
/LPDDR5/LPDDR5_B.DQ12: U37.Y5 (DQ12_B); also elsewhere on the board
/LPDDR5/LPDDR5_B.DQ13: U37.W6 (DQ13_B); also elsewhere on the board
/LPDDR5/LPDDR5_B.DQ14: U37.U6 (DQ14_B); also elsewhere on the board
/LPDDR5/LPDDR5_B.DQ15: U37.T5 (DQ15_B); also elsewhere on the board
/LPDDR5/LPDDR5_B.RDQS0_N: U37.W12 (RDQS0_c_B); also elsewhere on the board
/LPDDR5/LPDDR5_B.RDQS0_P: U37.Y13 (RDQS0_t_B); also elsewhere on the board
/LPDDR5/LPDDR5_B.RDQS1_N: U37.W4 (RDQS1_c_B); also elsewhere on the board
/LPDDR5/LPDDR5_B.RDQS1_P: U37.Y3 (RDQS1_t_B); also elsewhere on the board
/LPDDR5/LPDDR5_B.WCK0_N: U37.V11 (WCK0_c_B); also elsewhere on the board
/LPDDR5/LPDDR5_B.WCK0_P: U37.U12 (WCK0_t_B); also elsewhere on the board
/LPDDR5/LPDDR5_B.WCK1_N: U37.V5 (WCK1_c_B); also elsewhere on the board
/LPDDR5/LPDDR5_B.WCK1_P: U37.U4 (WCK1_t_B); also elsewhere on the board
/LPDDR5/LPDDR5_nRTS: U37.H1 (RESET_n); also elsewhere on the board
unnamed: L4.1, U38.3 (SW)
VDD2_DDR_S3: C292.1, C293.1, C296.1, C297.1, C300.1, C301.1, C304.1, C305.1, C308.1, C309.1, C312.1, C313.1, C314.1, C315.1, C316.1, C317.1, C318.1, C319.1, C320.1, C321.1, C323.1, C324.1, C326.1, C327.1, C328.1, C329.1, C330.1, C331.1, U37.A7 (VDD2H), U37.A8 (VDD2H), U37.A9 (VDD2H), U37.AA7 (VDD2H), U37.AA8 (VDD2H), U37.AA9 (VDD2H), U37.B7 (VDD2H), U37.B9 (VDD2H), U37.C7 (VDD2H), U37.C9 (VDD2H), U37.D8 (VDD2H), U37.E7 (VDD2H), U37.E9 (VDD2H), U37.F6 (VDD2H), U37.F7 (VDD2H), U37.F9 (VDD2H), U37.F10 (VDD2H), U37.J5 (VDD2H), U37.J11 (VDD2H), U37.K1 (VDD2H), U37.K2 (VDD2H), U37.K3 (VDD2H), U37.K4 (VDD2H), U37.K5 (VDD2H), U37.K6 (VDD2H), U37.K10 (VDD2H), U37.K11 (VDD2H), U37.K12 (VDD2H), U37.K13 (VDD2H), U37.K14 (VDD2H), U37.K15 (VDD2H), U37.L6 (VDD2H), U37.L7 (VDD2H), U37.L8 (VDD2H), U37.L9 (VDD2H), U37.L10 (VDD2H), U37.M1 (VDD2H), U37.M2 (VDD2H), U37.M3 (VDD2H), U37.M4 (VDD2H), U37.M5 (VDD2H), U37.M6 (VDD2H), U37.M10 (VDD2H), U37.M11 (VDD2H), U37.M12 (VDD2H), U37.M13 (VDD2H), U37.M14 (VDD2H), U37.M15 (VDD2H), U37.N5 (VDD2H), U37.N11 (VDD2H), U37.T6 (VDD2H), U37.T7 (VDD2H), U37.T9 (VDD2H), U37.T10 (VDD2H), U37.U7 (VDD2H), U37.U9 (VDD2H), U37.V8 (VDD2H), U37.W7 (VDD2H), U37.W9 (VDD2H), U37.Y7 (VDD2H), U37.Y9 (VDD2H); also elsewhere on the board

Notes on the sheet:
0.9V NOM
1.05V NOM
0.51V NOM
Buck to 2V
LPDDR5 Channel B
LPDDR5 Power
LPDDR5
LPDDR5 Channel A

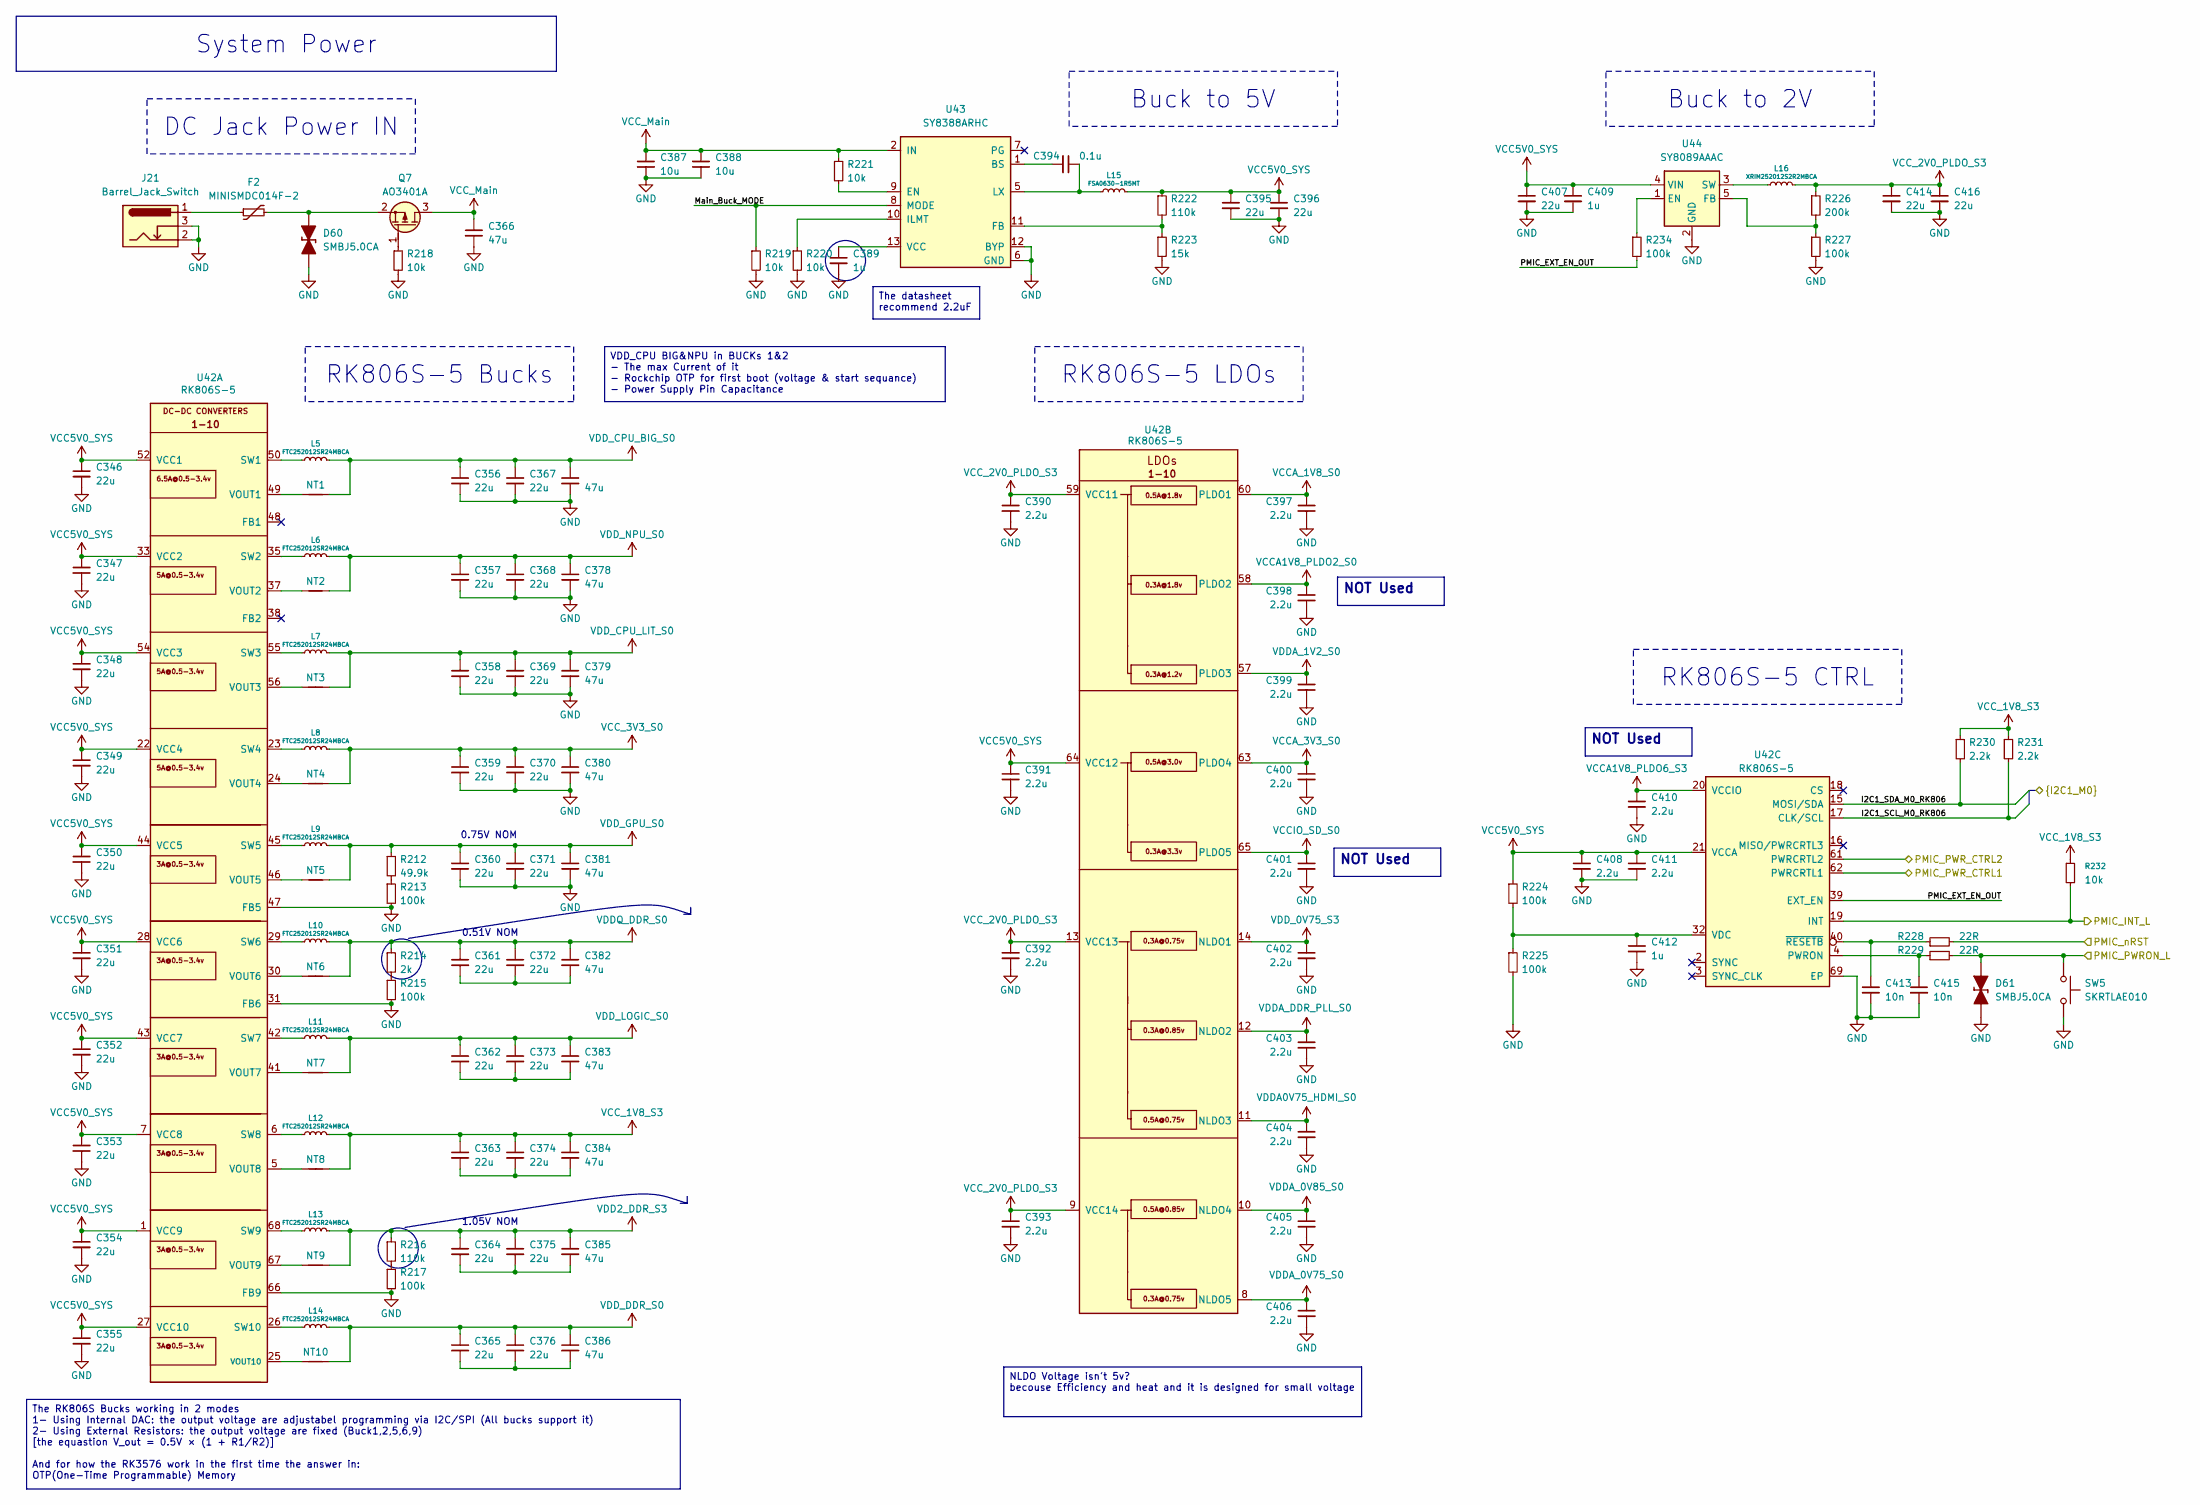
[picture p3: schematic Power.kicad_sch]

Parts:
C346, C347, C348, C349, C350, C351, C352, C353, C354, C355, C356, C357, C358, C359, C360, C361, C362, C363, C364, C365, C367, C368, C369, C370, C371, C372, C373, C374, C375, C376, C395, C396, C407, C414, C416: 22u; C_0603_1608Metric; Mouser Part CL10A226MP8NUNE; LCSC Part C86295
C366, C377, C378, C379, C380, C381, C382, C383, C384, C385, C386: 47u; C_0805_2012Metric; Mouser Part 187-CL21A476MQYNNNE; LCSC Part C16780
C387, C388: 10u; C_0603_1608Metric; Mouser Part 187-CL10A106KP8NNNC; LCSC Part C19702
C389, C409, C412: 1u; C_0201_0603Metric_Pad0.64x0.40mm_HandSolder; Mouser Part CL03A105KP3NSNC; LCSC Part C5209398
C390, C391, C392, C393, C397, C398, C399, C400, C401, C402, C403, C404, C405, C406, C408, C410, C411: 2.2u; C_0402_1005Metric; Mouser Part 187-CL05A225KO5NQNC; LCSC Part C170151
C394: 0.1u; C_0201_0603Metric_Pad0.64x0.40mm_HandSolder; Mouser Part 603-CC0201KRX56BB224; LCSC Part C326658
C413, C415: 10n; C_0201_0603Metric_Pad0.64x0.40mm_HandSolder; Mouser Part 187-CL03B103KP3NNNC; LCSC Part C87461
D60, D61: SMBJ5.0CA; D_SMB_TVS; Mouser Part 581-SMBJ5.0CA; LCSC Part C113975
F2: MINISMDC014F-2; Fuse_1812_4532Metric; LCSC Part C28326708
J21: Barrel_Jack_Switch; DC-JACK-TH-2.5_HC-DC-007B-2.5; LCSC Part C3010538
L5, L6, L7, L8, L9, L10, L11, L12, L13, L14: FTC252012SR24MBCA; L_1008_2520Metric; LCSC Part C5832366
L15: FSA0630-1R5MT; L_Sunlord_MWSA0603S; LCSC Part C41384300
L16: XRIM252012S2R2MBCA; L_1008_2520Metric; LCSC Part C22471111
NT1, NT2, NT3, NT4, NT5, NT6, NT7, NT8, NT9, NT10: NetTie_2; NetTie-2_SMD_Pad0.5mm
Q7: AO3401A; SOT-23; LCSC Part C347476
R212: 49.9k; R_0402_1005Metric; Mouser Part 603-RC0402FR-0749K9L; LCSC Part C137969
R213, R215, R217, R224, R225, R227, R234: 100k; R_0402_1005Metric; Mouser Part 603-RC0402FR-0710KL; LCSC Part C60490
R214: 2k; R_0402_1005Metric; Mouser Part 603AC0402FR-072KL; LCSC Part C144770
R216, R222: 110k; R_0402_1005Metric; Mouser Part 603-RC0402FR-07110KL; LCSC Part C138065
R218, R219, R220, R221, R232: 10k; R_0402_1005Metric; Mouser Part 603-RC0402FR-0710KL; LCSC Part C60490
R223: 15k; R_0402_1005Metric; Mouser Part 603-RC0402FR-0710KL; LCSC Part C60490
R226: 200k; R_0402_1005Metric; Mouser Part 603-RC0402FR-0710KL; LCSC Part C60490
R228, R229: 22R; R_0402_1005Metric; Mouser Part 603-RC0402FR-070RL; LCSC Part C106231
R230, R231: 2.2k; R_0402_1005Metric; Mouser Part 603-RC0402FR-072K2L; LCSC Part C114762
SW5: SKRTLAE010; LCSC Part C110293
U42: RK806S-5; ArtInChip_QFN-68-1EP_7x7mm_P0.35mm_EP5.49x5.49mm; LCSC Part C49174044
U43: SY8388ARHC; QFN-16-2.5x2.5-EP_SY8388ARHC; LCSC Part C5110279
U44: SY8089AAAC; SOT-23-5; LCSC Part C78988

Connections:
/Power/I2C1_SCL_M0_RK806: R231.2, U42.17 (CLK/SCL); also elsewhere on the board
/Power/I2C1_SDA_M0_RK806: R230.2, U42.15 (MOSI/SDA); also elsewhere on the board
/Power/Main_Buck_MODE: R219.1, U43.8 (MODE)
/Power/PMIC_EXT_EN_OUT: R234.2, U42.39 (EXT_EN)
/Power/PMIC_INT_L: R232.2, U42.19 (INT); also elsewhere on the board
/Power/PMIC_PWRON_L: D61.2 (A), R229.2, SW5.1; also elsewhere on the board
/Power/PMIC_PWR_CTRL1: U42.62 (PWRCRTL1); also elsewhere on the board
/Power/PMIC_PWR_CTRL2: U42.61 (PWRCRTL2); also elsewhere on the board
/Power/PMIC_nRST: R228.2; also elsewhere on the board
unnamed: C361.2, C372.2, C382.2
unnamed: C362.2, C373.2, C383.2
unnamed: C363.2, C374.2, C384.2
unnamed: C364.2, C375.2, C385.2
unnamed: C365.2, C376.2, C386.2
unnamed: C394.1, L15.1, U43.5 (LX), U43.15 (LX), U43.16 (LX)
unnamed: D60.2 (A), F2.2, Q7.2 (S)
unnamed: F2.1, J21.1
unnamed: L5.1, U42.50 (SW1), U42.51 (SW1)
unnamed: L6.1, U42.35 (SW2), U42.36 (SW2)
unnamed: Q7.1 (G), R218.1
unnamed: R212.2, R213.1
unnamed: R214.2, R215.1
unnamed: R216.2, R217.1
unnamed: L7.1, U42.55 (SW3)
unnamed: L8.1, U42.23 (SW4)
unnamed: L9.1, U42.45 (SW5)
unnamed: L10.1, U42.29 (SW6)
unnamed: L11.1, U42.42 (SW7)
unnamed: L12.1, U42.6 (SW8)
unnamed: L13.1, U42.68 (SW9)
unnamed: L14.1, U42.26 (SW10)
unnamed: NT1.1, U42.49 (VOUT1)
unnamed: NT2.1, U42.37 (VOUT2)
unnamed: NT3.1, U42.56 (VOUT3)
unnamed: NT4.1, U42.24 (VOUT4)
unnamed: NT5.1, U42.46 (VOUT5)
unnamed: NT6.1, U42.30 (VOUT6)
unnamed: NT7.1, U42.41 (VOUT7)
unnamed: NT8.1, U42.5 (VOUT8)
unnamed: NT9.1, U42.67 (VOUT9)
unnamed: NT10.1, U42.25 (VOUT10)
unnamed: C415.1, R229.1, U42.4 (PWRON)
unnamed: C412.1, R224.2, R225.1, U42.32 (VDC)
unnamed: C413.1, R228.1, U42.40 (~RESETB)
unnamed: C394.2, U43.1 (BS)
unnamed: R221.2, U43.9 (EN)
unnamed: R222.2, R223.1, U43.11 (FB)
unnamed: R220.1, U43.10 (ILMT)
unnamed: C389.1, U43.13 (VCC)
unnamed: R234.1, U44.1 (EN)
unnamed: R226.2, R227.1, U44.5 (FB)
unnamed: L16.1, U44.3 (SW)
VCCA1V8_PLDO2_S0: C398.1, U42.58 (PLDO2)
VCCA1V8_PLDO6_S3: C410.1, U42.20 (VCCIO)
VCCIO_SD_S0: C401.1, U42.65 (PLDO5)
VDD2_DDR_S3: C364.1, C375.1, C385.1, L13.2, NT9.2, R216.1; also elsewhere on the board
VDDA0V75_HDMI_S0: C404.1, U42.11 (NLDO3); also elsewhere on the board
VDDA_0V75_S0: C406.1, U42.8 (NLDO5); also elsewhere on the board
VDDA_0V85_S0: C405.1, U42.10 (NLDO4); also elsewhere on the board
VDDA_1V2_S0: C399.1, U42.57 (PLDO3); also elsewhere on the board
VDDA_DDR_PLL_S0: C403.1, U42.12 (NLDO2); also elsewhere on the board
VDD_0V75_S3: C402.1, U42.14 (NLDO1)
VDD_CPU_BIG_S0: C356.1, C367.1, C377.1, L5.2, NT1.2; also elsewhere on the board
VDD_CPU_LIT_S0: C358.1, C369.1, C379.1, L7.2, NT3.2; also elsewhere on the board
VDD_DDR_S0: C365.1, C376.1, C386.1, L14.2, NT10.2; also elsewhere on the board
VDD_GPU_S0: C360.1, C371.1, C381.1, L9.2, NT5.2, R212.1; also elsewhere on the board
VDD_LOGIC_S0: C362.1, C373.1, C383.1, L11.2, NT7.2; also elsewhere on the board
VDD_NPU_S0: C357.1, C368.1, C378.1, L6.2, NT2.2; also elsewhere on the board

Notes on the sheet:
1.05V NOM
0.51V NOM
0.75V NOM
VDD_CPU BIG&NPU in BUCKs 1&2 - The max Current of it - Rockchip OTP for first boot (voltage & start sequance) - Power Supply Pin Capacitance
RK806S-5 LDOs
The datasheet recommend 2.2uF
NLDO Voltage isn't 5v? becouse Efficiency and heat and it is designed for small voltage
The RK806S Bucks working in 2 modes 1- Using Internal DAC: the output voltage are adjustabel programming via I2C/SPI (All bucks support it) 2- Using External Resistors: the output voltage are fixed (Buck1,2,5,6,9) [the equastion V_out = 0.5V × (1 + R1/R2)] And for how the RK3576 work in the first t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
Buck to 2V
RK806S-5 Bucks
System Power
NOT Used
DC Jack Power IN
RK806S-5 CTRL
Buck to 5V

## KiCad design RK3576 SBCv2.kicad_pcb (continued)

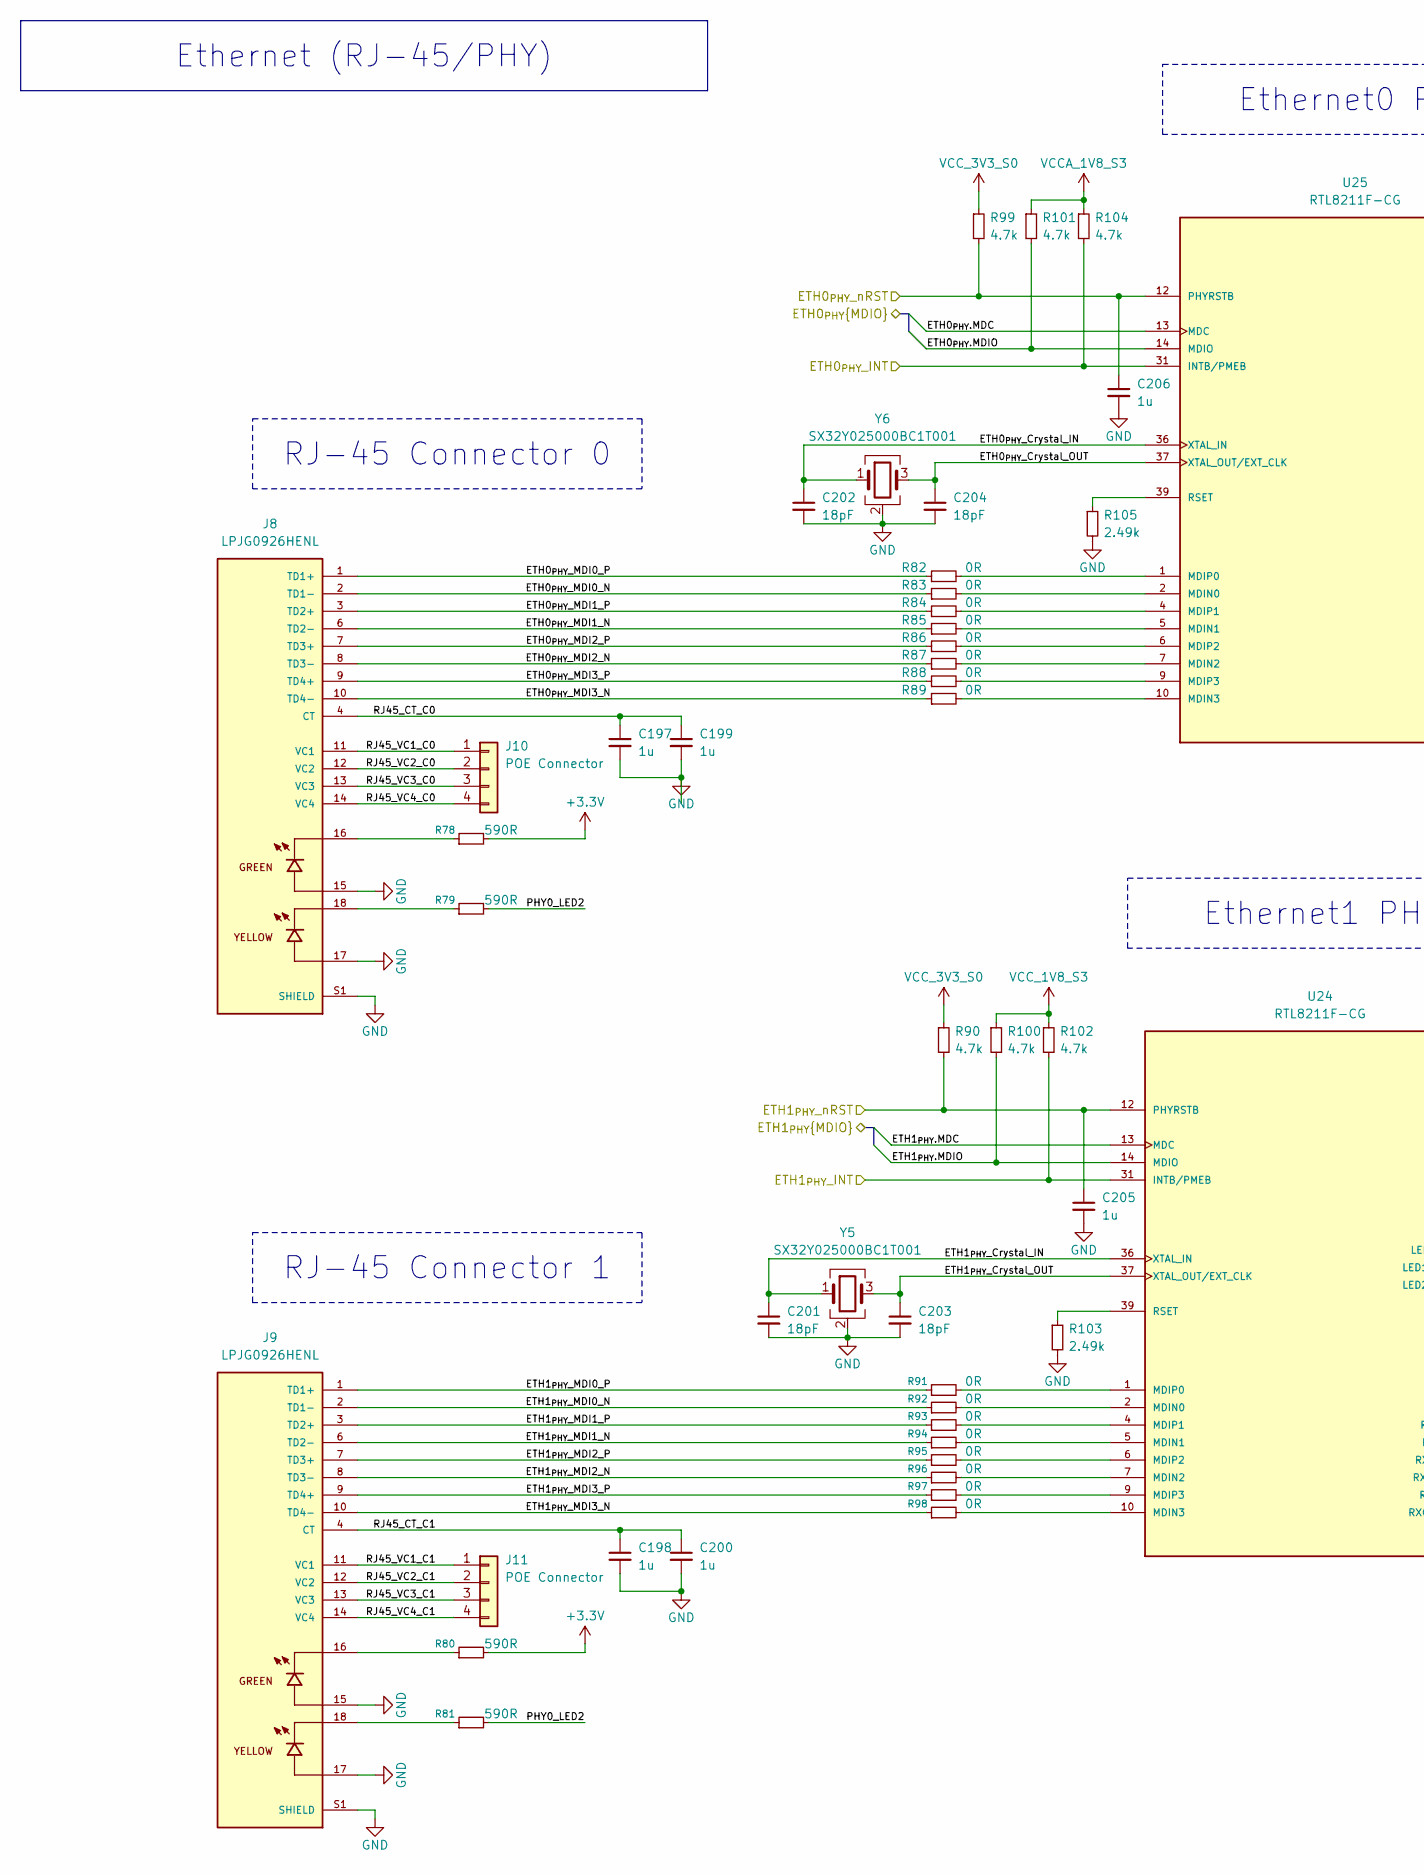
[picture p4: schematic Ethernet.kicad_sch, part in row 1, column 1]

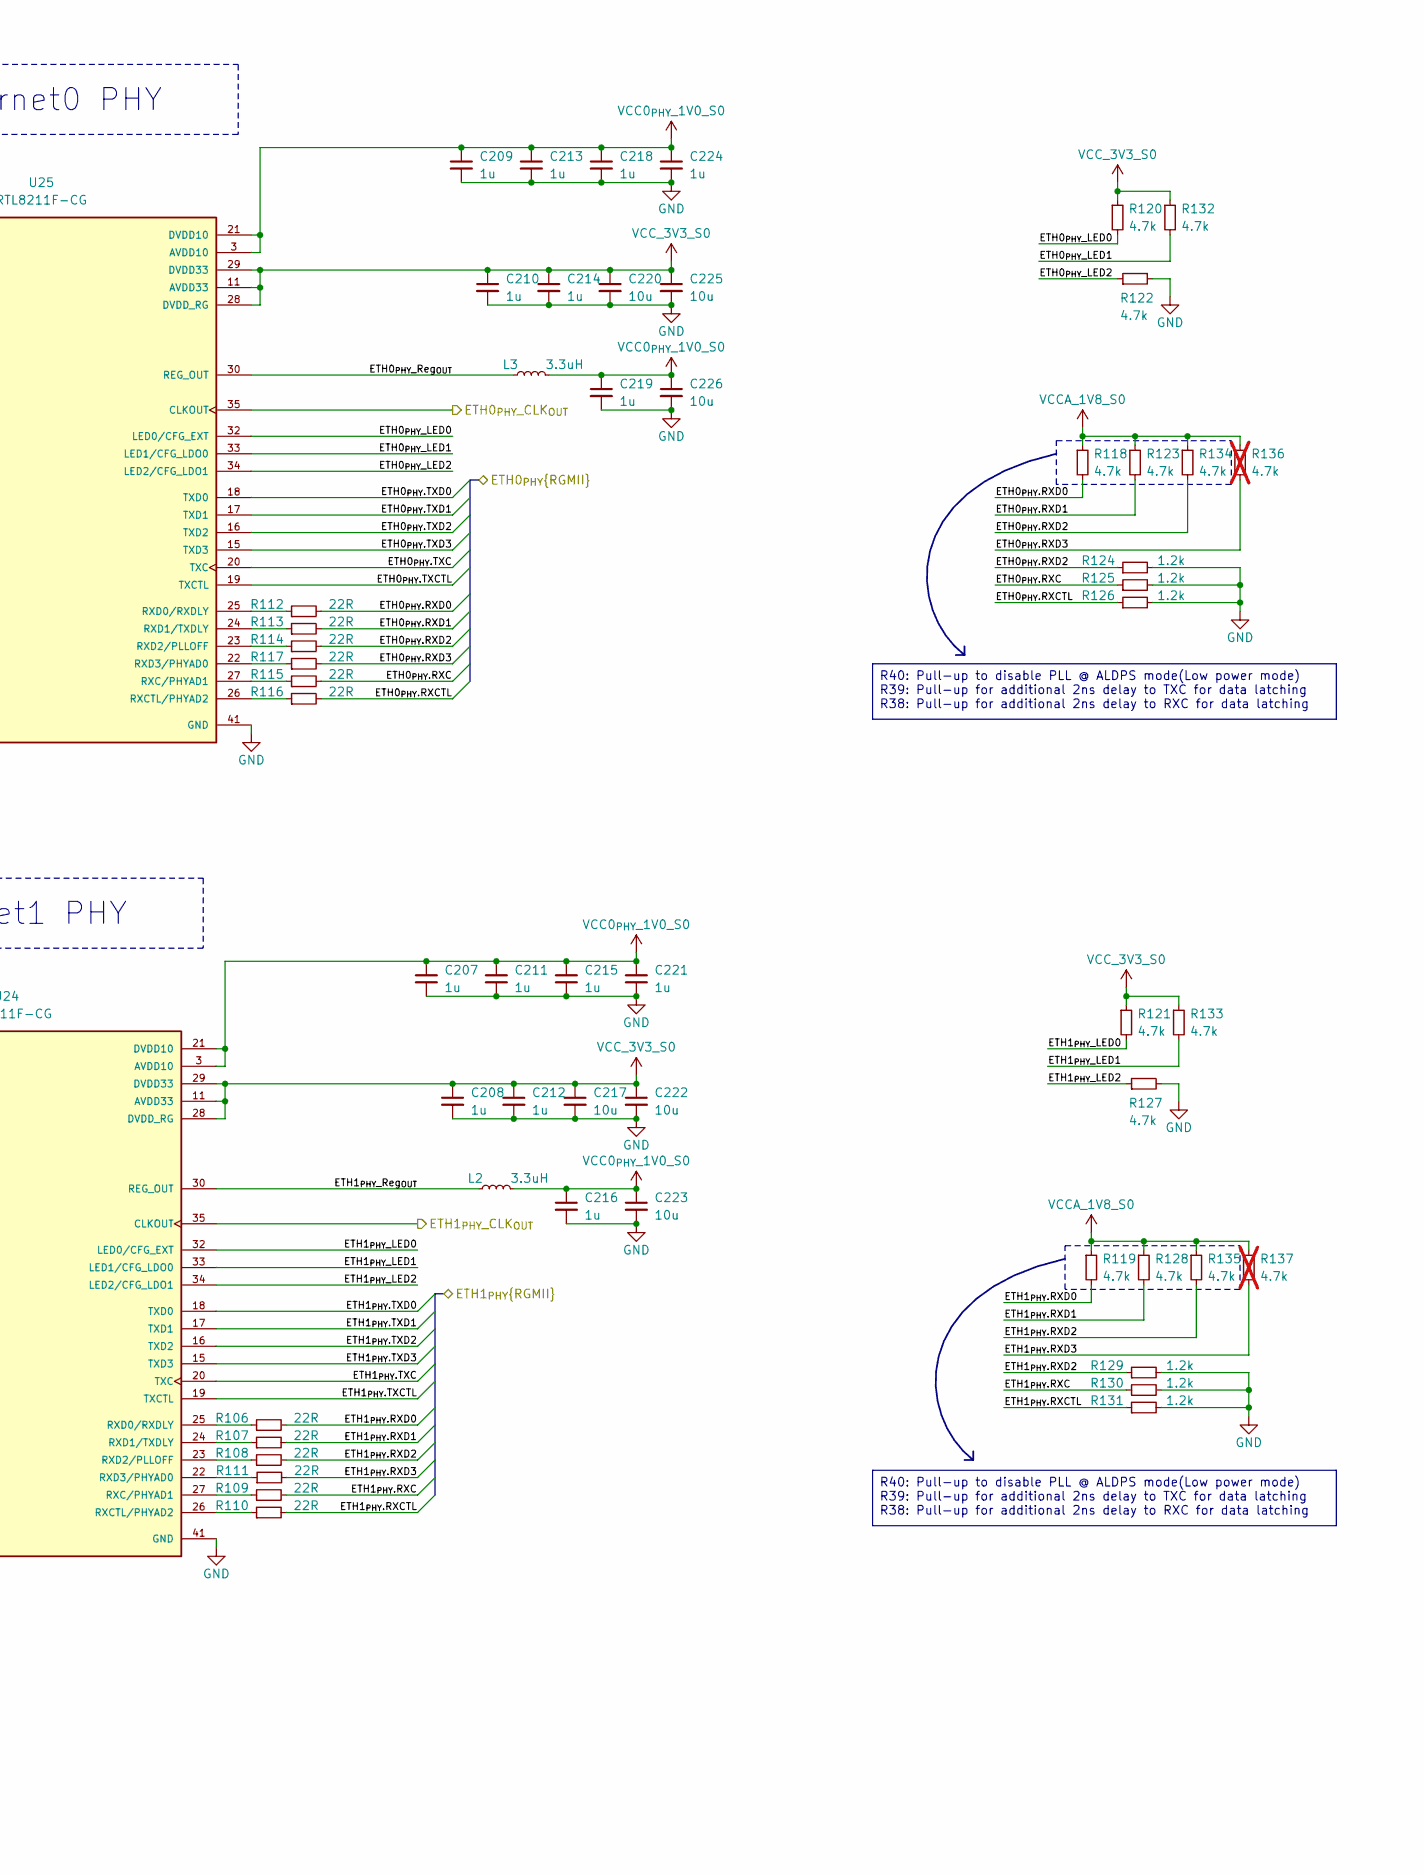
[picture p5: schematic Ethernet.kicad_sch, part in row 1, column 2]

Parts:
C197, C198, C199, C200, C205, C206, C207, C208, C209, C210, C211, C212, C213, C214, C215, C216, C218, C219, C221, C224: 1u; C_0201_0603Metric_Pad0.64x0.40mm_HandSolder; Mouser Part CL03A105KP3NSNC; LCSC Part C5209398
C201, C202, C203, C204: 18pF; C_0402_1005Metric; Mouser Part 603-CC402FRNPO9BN180; LCSC Part C541431
C217, C220, C222, C223, C225, C226: 10u; C_0603_1608Metric; Mouser Part 187-CL10A106KP8NNNC; LCSC Part C19702
J8, J9: LPJG0926HENL; PARTREV A; LCSC Part C22457393
J10, J11: POE Connector; PinHeader_2x02_P2.54mm_Vertical; Mouser Part 200-TSW10207GDLL001; LCSC Part C66690
L2, L3: 3.3uH; L_Coilcraft_0805HQ_2012Metric; LCSC Part C2926398
R78, R79, R80, R81: 590R; R_0402_1005Metric; Mouser Part 603-RC0402FR-07590RL; LCSC Part C327335
R82, R83, R84, R85, R86, R87, R88, R89, R91, R92, R93, R94, R95, R96, R97, R98: 0R; R_0402_1005Metric; Mouser Part 603-RC0402FR-070RL; LCSC Part C106231
R90, R99, R100, R101, R102, R104, R118, R119, R120, R121, R122, R123, R127, R128, R132, R133, R134, R135: 4.7k; R_0402_1005Metric; Mouser Part 603-RC0402FR-074K7L; LCSC Part C105871
R103, R105: 2.49k; R_0402_1005Metric; Mouser Part 603-RC0402FR-074K7L; LCSC Part C105871
R106, R107, R108, R109, R110, R111, R112, R113, R114, R115, R116, R117: 22R; R_0402_1005Metric; Mouser Part 603-RC0402FR-070RL; LCSC Part C106231
R124, R125, R126, R129, R130, R131: 1.2k; R_0402_1005Metric; Mouser Part 603-RC0402FR-071K2L; LCSC Part C138040
R136, R137: 4.7k; R_0402_1005Metric; Mouser Part 603-RC0402FR-074K7L; LCSC Part C105871; not fitted
U24, U25: RTL8211F-CG; RTL8211F-CG_QFN-40-1EP_5x5mm_P0.4mm; PARTREV 1.4; LCSC Part C187932
Y5, Y6: SX32Y025000BC1T001; Crystal_SMD_3225-4Pin_3.2x2.5mm_HandSoldering; LCSC Part C20612981

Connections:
/Ethernet/ETH0_{PHY}.MDC: U25.13 (MDC); also elsewhere on the board
/Ethernet/ETH0_{PHY}.MDIO: R101.2, U25.14 (MDIO); also elsewhere on the board
/Ethernet/ETH0_{PHY}.RXC: R115.2, R125.1; also elsewhere on the board
/Ethernet/ETH0_{PHY}.RXCTL: R116.2, R126.1; also elsewhere on the board
/Ethernet/ETH0_{PHY}.RXD0: R112.2, R118.2; also elsewhere on the board
/Ethernet/ETH0_{PHY}.RXD1: R113.2, R123.2; also elsewhere on the board
/Ethernet/ETH0_{PHY}.RXD2: R114.2, R124.1, R134.2; also elsewhere on the board
/Ethernet/ETH0_{PHY}.RXD3: R117.2, R136.2; also elsewhere on the board
/Ethernet/ETH0_{PHY}.TXC: U25.20 (TXC); also elsewhere on the board
/Ethernet/ETH0_{PHY}.TXCTL: U25.19 (TXCTL); also elsewhere on the board
/Ethernet/ETH0_{PHY}.TXD0: U25.18 (TXD0); also elsewhere on the board
/Ethernet/ETH0_{PHY}.TXD1: U25.17 (TXD1); also elsewhere on the board
/Ethernet/ETH0_{PHY}.TXD2: U25.16 (TXD2); also elsewhere on the board
/Ethernet/ETH0_{PHY}.TXD3: U25.15 (TXD3); also elsewhere on the board
/Ethernet/ETH0_{PHY}_CLK_{OUT}: U25.35 (CLKOUT); also elsewhere on the board
/Ethernet/ETH0_{PHY}_Crystal_IN: C202.1, U25.36 (XTAL_IN), Y6.1
/Ethernet/ETH0_{PHY}_Crystal_OUT: C204.1, U25.37 (XTAL_OUT/EXT_CLK), Y6.3
/Ethernet/ETH0_{PHY}_INT: R104.2, U25.31 (INTB/PMEB); also elsewhere on the board
/Ethernet/ETH0_{PHY}_LED0: R120.2, U25.32 (LED0/CFG_EXT)
/Ethernet/ETH0_{PHY}_LED1: R132.2, U25.33 (LED1/CFG_LDO0)
/Ethernet/ETH0_{PHY}_LED2: R122.1, U25.34 (LED2/CFG_LDO1)
/Ethernet/ETH0_{PHY}_MDI0_N: J8.2 (TD1-), R83.1
/Ethernet/ETH0_{PHY}_MDI0_P: J8.1 (TD1+), R82.1
/Ethernet/ETH0_{PHY}_MDI1_N: J8.6 (TD2-), R85.1
/Ethernet/ETH0_{PHY}_MDI1_P: J8.3 (TD2+), R84.1
/Ethernet/ETH0_{PHY}_MDI2_N: J8.8 (TD3-), R87.1
/Ethernet/ETH0_{PHY}_MDI2_P: J8.7 (TD3+), R86.1
/Ethernet/ETH0_{PHY}_MDI3_N: J8.10 (TD4-), R89.1
/Ethernet/ETH0_{PHY}_MDI3_P: J8.9 (TD4+), R88.1
/Ethernet/ETH0_{PHY}_Reg_{OUT}: L3.1, U25.30 (REG_OUT)
/Ethernet/ETH0_{PHY}_nRST: C206.1, R99.2, U25.12 (PHYRSTB); also elsewhere on the board
/Ethernet/ETH1_{PHY}.MDC: U24.13 (MDC); also elsewhere on the board
/Ethernet/ETH1_{PHY}.MDIO: R100.2, U24.14 (MDIO); also elsewhere on the board
/Ethernet/ETH1_{PHY}.RXC: R109.2, R130.1; also elsewhere on the board
/Ethernet/ETH1_{PHY}.RXCTL: R110.2, R131.1; also elsewhere on the board
/Ethernet/ETH1_{PHY}.RXD0: R106.2, R119.2; also elsewhere on the board
/Ethernet/ETH1_{PHY}.RXD1: R107.2, R128.2; also elsewhere on the board
/Ethernet/ETH1_{PHY}.RXD2: R108.2, R129.1, R135.2; also elsewhere on the board
/Ethernet/ETH1_{PHY}.RXD3: R111.2, R137.2; also elsewhere on the board
/Ethernet/ETH1_{PHY}.TXC: U24.20 (TXC); also elsewhere on the board
/Ethernet/ETH1_{PHY}.TXCTL: U24.19 (TXCTL); also elsewhere on the board
/Ethernet/ETH1_{PHY}.TXD0: U24.18 (TXD0); also elsewhere on the board
/Ethernet/ETH1_{PHY}.TXD1: U24.17 (TXD1); also elsewhere on the board
/Ethernet/ETH1_{PHY}.TXD2: U24.16 (TXD2); also elsewhere on the board
/Ethernet/ETH1_{PHY}.TXD3: U24.15 (TXD3); also elsewhere on the board
/Ethernet/ETH1_{PHY}_CLK_{OUT}: U24.35 (CLKOUT); also elsewhere on the board
/Ethernet/ETH1_{PHY}_Crystal_IN: C201.1, U24.36 (XTAL_IN), Y5.1
/Ethernet/ETH1_{PHY}_Crystal_OUT: C203.1, U24.37 (XTAL_OUT/EXT_CLK), Y5.3
/Ethernet/ETH1_{PHY}_INT: R102.2, U24.31 (INTB/PMEB); also elsewhere on the board
/Ethernet/ETH1_{PHY}_LED0: R121.2, U24.32 (LED0/CFG_EXT)
/Ethernet/ETH1_{PHY}_LED1: R133.2, U24.33 (LED1/CFG_LDO0)
/Ethernet/ETH1_{PHY}_LED2: R127.1, U24.34 (LED2/CFG_LDO1)
/Ethernet/ETH1_{PHY}_MDI0_N: J9.2 (TD1-), R92.1
/Ethernet/ETH1_{PHY}_MDI0_P: J9.1 (TD1+), R91.1
/Ethernet/ETH1_{PHY}_MDI1_N: J9.6 (TD2-), R94.1
/Ethernet/ETH1_{PHY}_MDI1_P: J9.3 (TD2+), R93.1
/Ethernet/ETH1_{PHY}_MDI2_N: J9.8 (TD3-), R96.1
/Ethernet/ETH1_{PHY}_MDI2_P: J9.7 (TD3+), R95.1
/Ethernet/ETH1_{PHY}_MDI3_N: J9.10 (TD4-), R98.1
/Ethernet/ETH1_{PHY}_MDI3_P: J9.9 (TD4+), R97.1
/Ethernet/ETH1_{PHY}_Reg_{OUT}: L2.1, U24.30 (REG_OUT)
/Ethernet/ETH1_{PHY}_nRST: C205.1, R90.2, U24.12 (PHYRSTB); also elsewhere on the board
/Ethernet/PHY0_LED2: R79.2, R81.2
/Ethernet/RJ45_CT_C0: C197.1, C199.1, J8.4 (CT), J8.5 (CT)
/Ethernet/RJ45_CT_C1: C198.1, C200.1, J9.4 (CT), J9.5 (CT)
/Ethernet/RJ45_VC1_C0: J8.11 (VC1), J10.1
/Ethernet/RJ45_VC1_C1: J9.11 (VC1), J11.1
/Ethernet/RJ45_VC2_C0: J8.12 (VC2), J10.2
/Ethernet/RJ45_VC2_C1: J9.12 (VC2), J11.2
/Ethernet/RJ45_VC3_C0: J8.13 (VC3), J10.3
/Ethernet/RJ45_VC3_C1: J9.13 (VC3), J11.3
/Ethernet/RJ45_VC4_C0: J8.14 (VC4), J10.4
/Ethernet/RJ45_VC4_C1: J9.14 (VC4), J11.4
unnamed: J8.16, R78.1
unnamed: J8.18, R79.1
unnamed: J9.16, R80.1
unnamed: J9.18, R81.1
unnamed: R92.2, U24.2 (MDIN0)
unnamed: R94.2, U24.5 (MDIN1)
unnamed: R96.2, U24.7 (MDIN2)
unnamed: R98.2, U24.10 (MDIN3)
unnamed: R91.2, U24.1 (MDIP0)
unnamed: R93.2, U24.4 (MDIP1)
unnamed: R95.2, U24.6 (MDIP2)
unnamed: R97.2, U24.9 (MDIP3)
unnamed: R103.1, U24.39 (RSET)
unnamed: R110.1, U24.26 (RXCTL/PHYAD2)
unnamed: R109.1, U24.27 (RXC/PHYAD1)
unnamed: R106.1, U24.25 (RXD0/RXDLY)
unnamed: R107.1, U24.24 (RXD1/TXDLY)
unnamed: R108.1, U24.23 (RXD2/PLLOFF)
unnamed: R111.1, U24.22 (RXD3/PHYAD0)
unnamed: R83.2, U25.2 (MDIN0)
unnamed: R85.2, U25.5 (MDIN1)
unnamed: R87.2, U25.7 (MDIN2)
unnamed: R89.2, U25.10 (MDIN3)
unnamed: R82.2, U25.1 (MDIP0)
unnamed: R84.2, U25.4 (MDIP1)
unnamed: R86.2, U25.6 (MDIP2)
unnamed: R88.2, U25.9 (MDIP3)
unnamed: R105.1, U25.39 (RSET)
unnamed: R116.1, U25.26 (RXCTL/PHYAD2)
unnamed: R115.1, U25.27 (RXC/PHYAD1)
unnamed: R112.1, U25.25 (RXD0/RXDLY)
unnamed: R113.1, U25.24 (RXD1/TXDLY)
unnamed: R114.1, U25.23 (RXD2/PLLOFF)
unnamed: R117.1, U25.22 (RXD3/PHYAD0)
VCC0_{PHY}_1V0_S0: C207.1, C209.1, C211.1, C213.1, C215.1, C216.1, C218.1, C219.1, C221.1, C223.1, C224.1, C226.1, L2.2, L3.2, U24.3 (AVDD10), U24.8 (AVDD10), U24.21 (DVDD10), U24.38 (AVDD10), U25.3 (AVDD10), U25.8 (AVDD10), U25.21 (DVDD10), U25.38 (AVDD10)
VCCA_1V8_S3: R101.1, R104.1; also elsewhere on the board

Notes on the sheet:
R40: Pull-up to disable PLL @ ALDPS mode(Low power mode) R39: Pull-up for additional 2ns delay to TXC for data latching R38: Pull-up for additional 2ns delay to RXC for data latching
RJ-45 Connector 1
Ethernet (RJ-45/PHY)
Ethernet1 PHY
Ethernet0 PHY
RJ-45 Connector 0

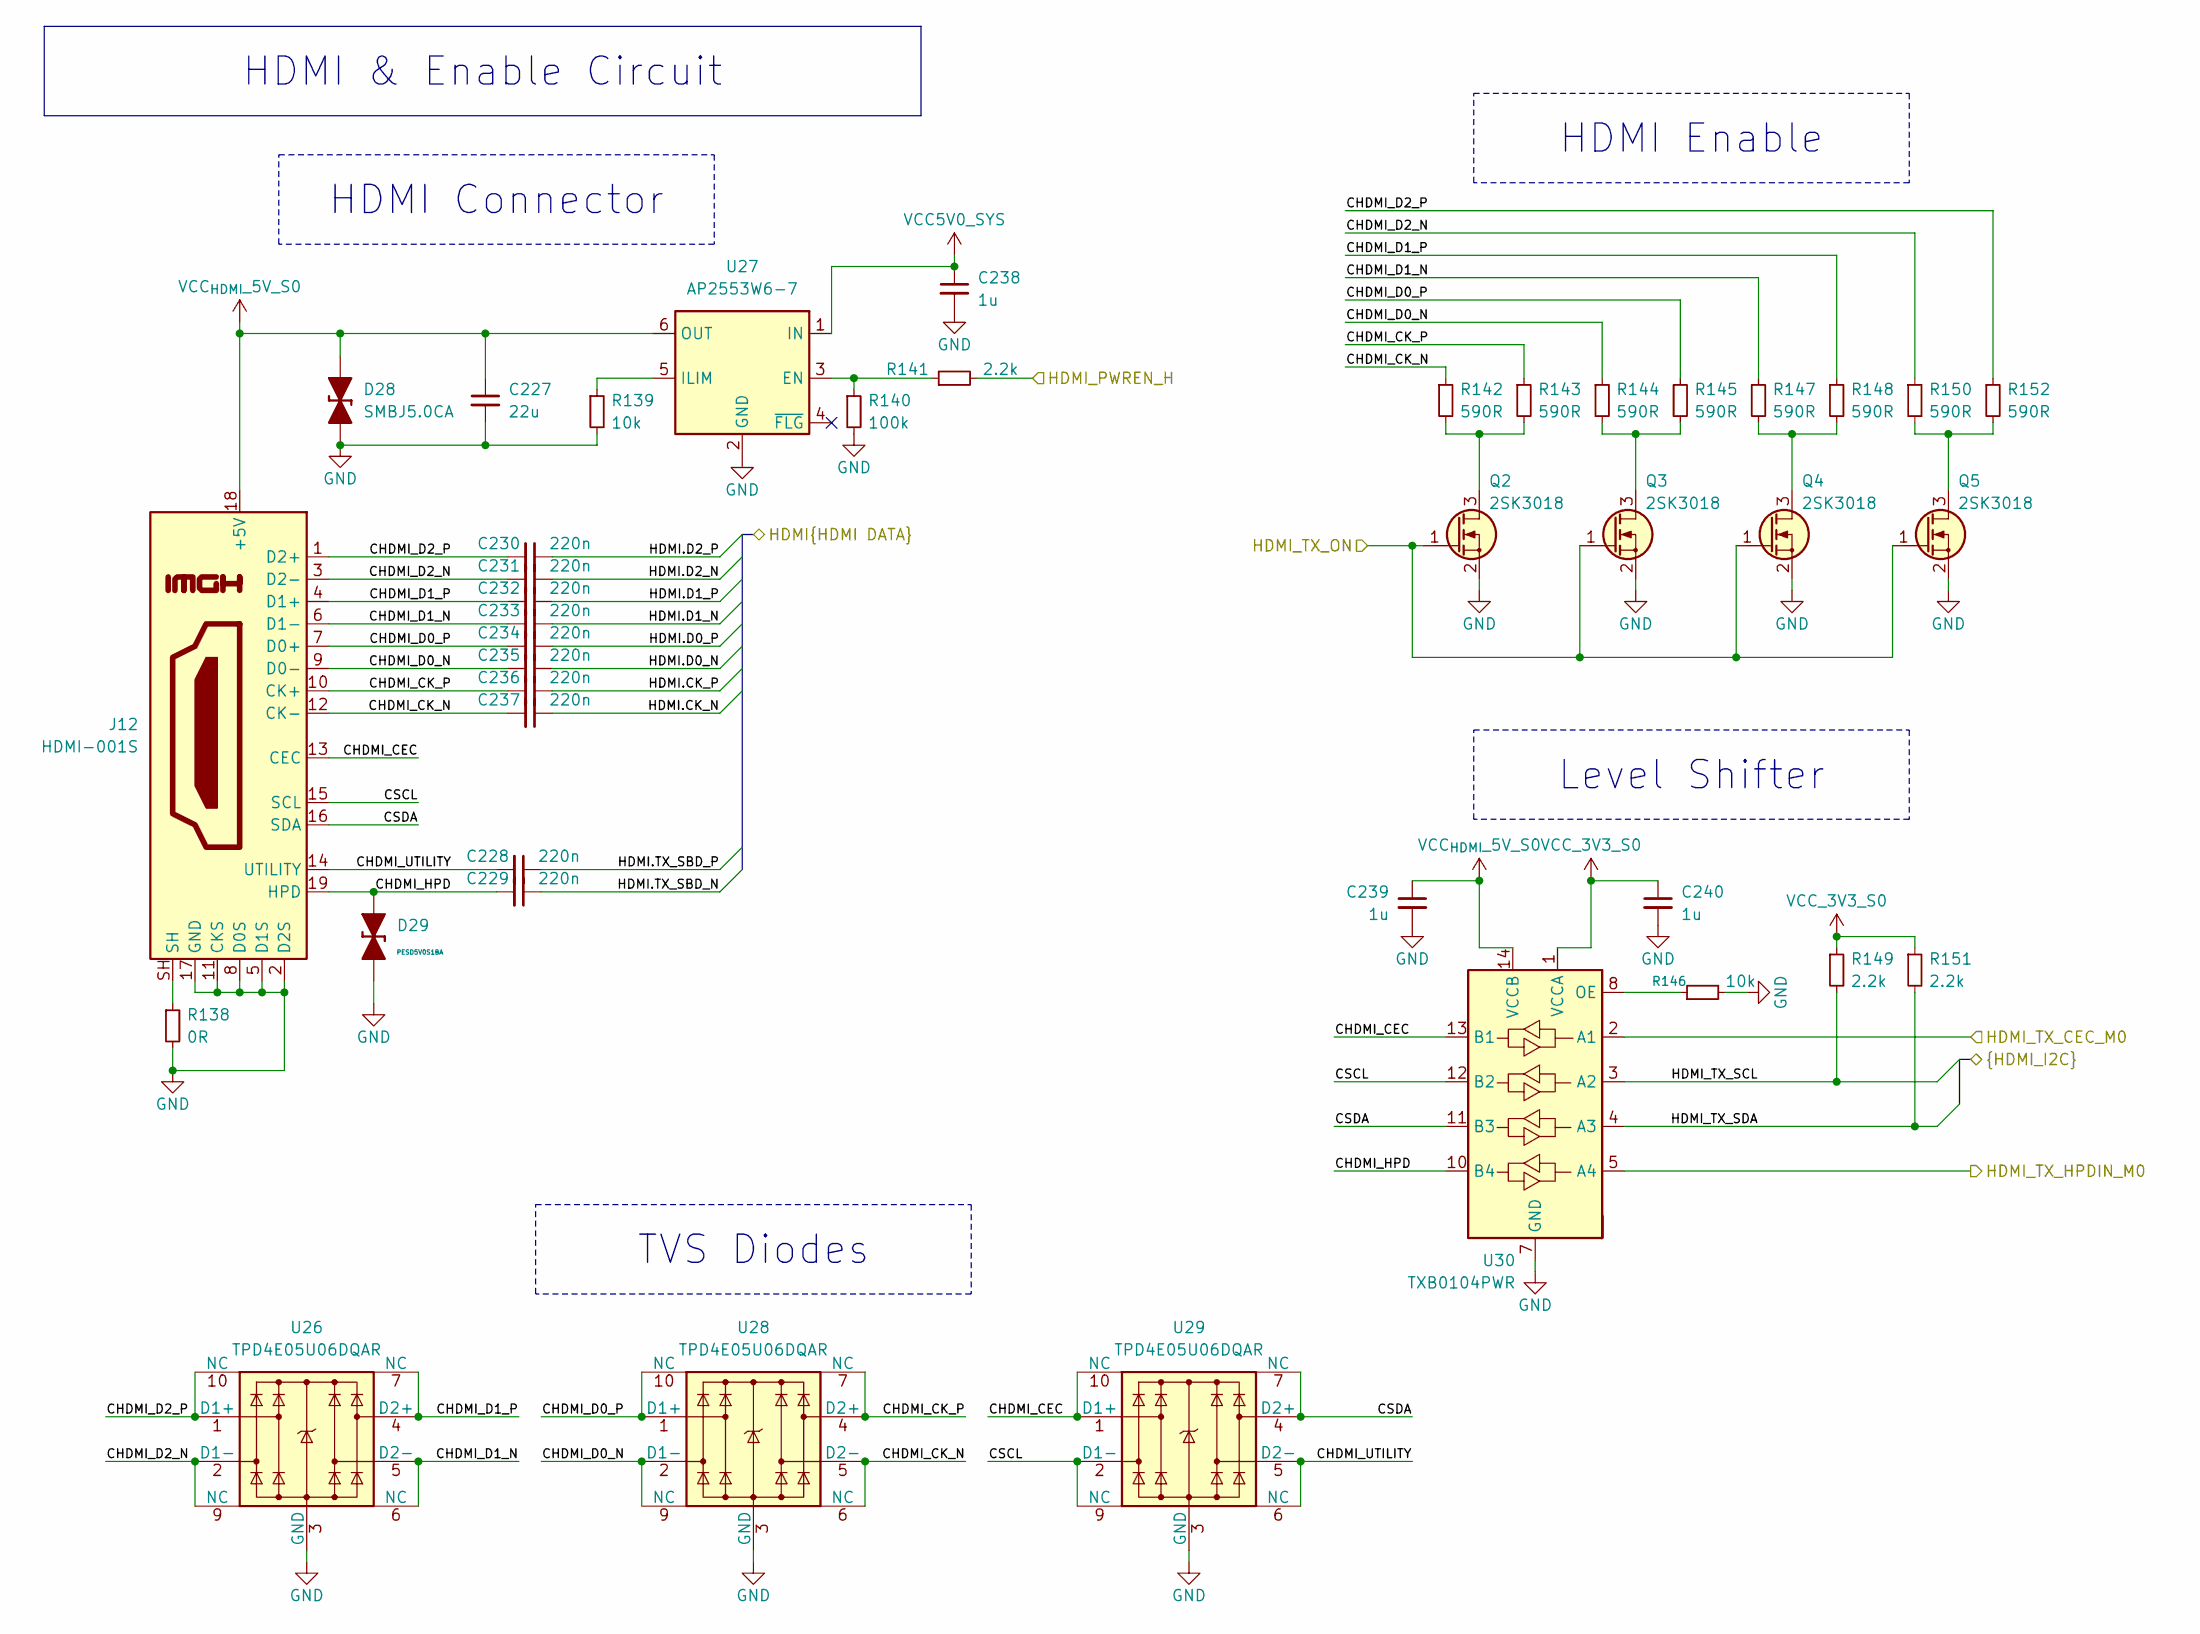
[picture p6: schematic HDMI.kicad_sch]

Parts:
C227: 22u; C_0603_1608Metric; Mouser Part CL10A226MP8NUNE; LCSC Part C86295
C228, C229, C230, C231, C232, C233, C234, C235, C236, C237: 220n; C_0201_0603Metric_Pad0.64x0.40mm_HandSolder; Mouser Part 603-CC0201KRX56BB224; LCSC Part C326658
C238, C239, C240: 1u; C_0201_0603Metric_Pad0.64x0.40mm_HandSolder; Mouser Part CL03A105KP3NSNC; LCSC Part C5209398
D28: SMBJ5.0CA; D_SMB_TVS; Mouser Part 581-SMBJ5.0CA; LCSC Part C113975
D29: PESD5V0S1BA; D_SOD-323_TVS; Mouser Part 771-PESD5V0S1BA-T/R; LCSC Part C5158048
J12: HDMI-001S; HDMI_A_Amphenol_10029449-x01xLF_Horizontal; LCSC Part C720616
Q2, Q3, Q4, Q5: 2SK3018; SOT-323_SC-70; LCSC Part C20069148
R138: 0R; R_0402_1005Metric; Mouser Part 603-RC0402FR-070RL; LCSC Part C106231
R139, R146: 10k; R_0402_1005Metric; Mouser Part 603-RC0402FR-0710KL; LCSC Part C60490
R140: 100k; R_0402_1005Metric; Mouser Part 603-RC0402FR-0710KL; LCSC Part C60490
R141, R149, R151: 2.2k; R_0402_1005Metric; Mouser Part 603-RC0402FR-072K2L; LCSC Part C114762
R142, R143, R144, R145, R147, R148, R150, R152: 590R; R_0402_1005Metric; Mouser Part 603-RC0402FR-07590RL; LCSC Part C327335
U26, U28, U29: TPD4E05U06DQAR; USON-10_2.5x1.0mm_P0.5mm; Mouser Part 595-TPD4E05U06DQAR; LCSC Part C138714
U27: AP2553W6-7; SOT-23-6_Handsoldering; Mouser Part 621-AP2553W6-7; LCSC Part C212302
U30: TXB0104PWR; TSSOP-14_4.4x5mm_P0.65mm; Mouser Part 595-TXB0104PWR; LCSC Part C60708

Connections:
/HDMI/CHDMI_CEC: J12.13 (CEC), U29.1 (D1+), U29.10 (NC), U30.13 (B1)
/HDMI/CHDMI_CK_N: C237.2, J12.12 (CK-), R142.1, U28.5 (D2-), U28.6 (NC)
/HDMI/CHDMI_CK_P: C236.2, J12.10 (CK+), R143.1, U28.4 (D2+), U28.7 (NC)
/HDMI/CHDMI_D0_N: C235.2, J12.9 (D0-), R144.1, U28.2 (D1-), U28.9 (NC)
/HDMI/CHDMI_D0_P: C234.2, J12.7 (D0+), R145.1, U28.1 (D1+), U28.10 (NC)
/HDMI/CHDMI_D1_N: C233.2, J12.6 (D1-), R147.1, U26.5 (D2-), U26.6 (NC)
/HDMI/CHDMI_D1_P: C232.2, J12.4 (D1+), R148.1, U26.4 (D2+), U26.7 (NC)
/HDMI/CHDMI_D2_N: C231.2, J12.3 (D2-), R150.1, U26.2 (D1-), U26.9 (NC)
/HDMI/CHDMI_D2_P: C230.2, J12.1 (D2+), R152.1, U26.1 (D1+), U26.10 (NC)
/HDMI/CHDMI_HPD: C229.2, D29.2 (A), J12.19 (HPD), U30.10 (B4)
/HDMI/CHDMI_UTILITY: C228.2, J12.14 (UTILITY), U29.5 (D2-), U29.6 (NC)
/HDMI/CSCL: J12.15 (SCL), U29.2 (D1-), U29.9 (NC), U30.12 (B2)
/HDMI/CSDA: J12.16 (SDA), U29.4 (D2+), U29.7 (NC), U30.11 (B3)
/HDMI/HDMI.CK_N: C237.1
/HDMI/HDMI.CK_P: C236.1
/HDMI/HDMI.D0_N: C235.1
/HDMI/HDMI.D0_P: C234.1
/HDMI/HDMI.D1_N: C233.1
/HDMI/HDMI.D1_P: C232.1
/HDMI/HDMI.D2_N: C231.1
/HDMI/HDMI.D2_P: C230.1
/HDMI/HDMI.TX_SBD_N: C229.1
/HDMI/HDMI.TX_SBD_P: C228.1
/HDMI/HDMI_PWREN_H: R141.2; also elsewhere on the board
/HDMI/HDMI_TX_CEC_M0: U30.2 (A1); also elsewhere on the board
/HDMI/HDMI_TX_HPDIN_M0: U30.5 (A4); also elsewhere on the board
/HDMI/HDMI_TX_ON: Q2.1 (G), Q3.1 (G), Q4.1 (G), Q5.1 (G); also elsewhere on the board
/HDMI/HDMI_TX_SCL: R149.2, U30.3 (A2); also elsewhere on the board
/HDMI/HDMI_TX_SDA: R151.2, U30.4 (A3); also elsewhere on the board
unnamed: J12.SH, R138.1
unnamed: Q2.3 (D), R142.2, R143.2
unnamed: Q3.3 (D), R144.2, R145.2
unnamed: Q4.3 (D), R147.2, R148.2
unnamed: Q5.3 (D), R150.2, R152.2
unnamed: R140.1, R141.1, U27.3 (EN)
unnamed: R139.1, U27.5 (ILIM)
unnamed: R146.1, U30.8 (OE)
VCC_{HDMI}_5V_S0: C227.1, C239.1, D28.2 (A), J12.18 (+5V), U27.6 (OUT), U30.14 (VCCB)

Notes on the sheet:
TVS Diodes
HDMI Connector
Level Shifter
HDMI & Enable Circuit
HDMI Enable

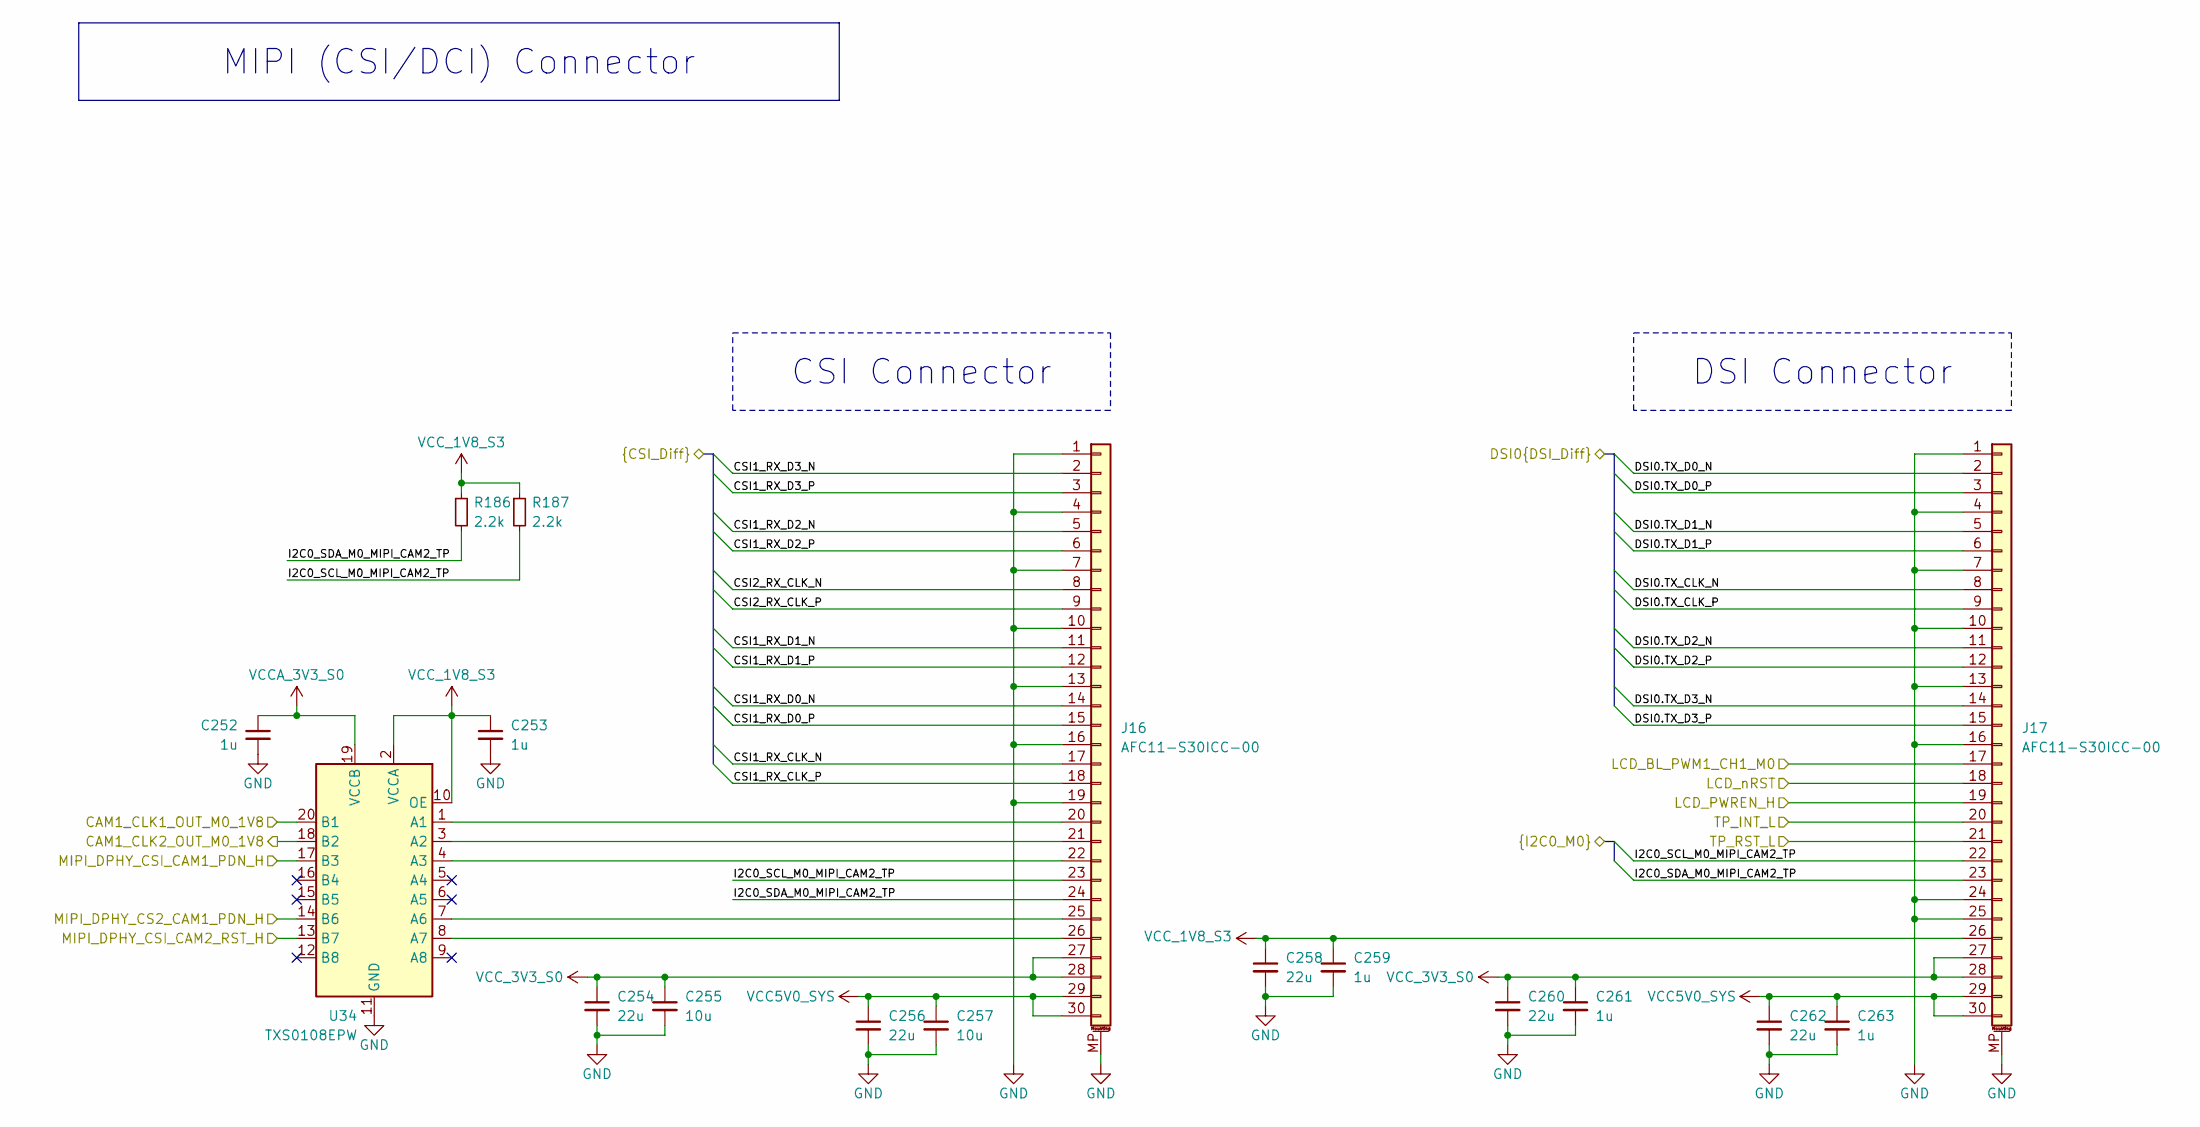
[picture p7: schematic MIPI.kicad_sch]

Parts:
C252, C253, C259, C261, C263: 1u; C_0201_0603Metric_Pad0.64x0.40mm_HandSolder; Mouser Part CL03A105KP3NSNC; LCSC Part C5209398
C254, C256, C258, C260, C262: 22u; C_0603_1608Metric; Mouser Part CL10A226MP8NUNE; LCSC Part C86295
C255, C257: 10u; C_0603_1608Metric; Mouser Part 187-CL10A106KP8NNNC; LCSC Part C19702
J16, J17: AFC11-S30ICC-00; FPC-SMD_30P-L20.5-W2.0-P0.50; Mouser Part 38-52559-3052; LCSC Part C11078
R186, R187: 2.2k; R_0402_1005Metric; Mouser Part 603-RC0402FR-072K2L; LCSC Part C114762
U34: TXS0108EPW; TXS0108ERGYR_VQFN-20-EP_C90706; Mouser Part TXS0108ERGYR; LCSC Part C90706

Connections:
/MIPI/CAM1_CLK1_OUT_M0_1V8: U34.20 (B1); also elsewhere on the board
/MIPI/CAM1_CLK2_OUT_M0_1V8: U34.18 (B2); also elsewhere on the board
/MIPI/CSI1_RX_CLK_N: J16.17
/MIPI/CSI1_RX_D0_N: J16.14
/MIPI/CSI1_RX_D1_P: J16.12
/MIPI/DSI0.TX_D2_P: J17.12; also elsewhere on the board
/MIPI/LCD_BL_PWM1_CH1_M0: J17.17; also elsewhere on the board
/MIPI/LCD_PWREN_H: J17.19; also elsewhere on the board
/MIPI/MIPI_DPHY_CS2_CAM1_PDN_H: U34.14 (B6); also elsewhere on the board
/MIPI/MIPI_DPHY_CSI_CAM1_PDN_H: U34.17 (B3); also elsewhere on the board
/MIPI/MIPI_DPHY_CSI_CAM2_RST_H: U34.13 (B7); also elsewhere on the board
unnamed: J16.22, U34.4 (A3)
unnamed: J16.25, U34.7 (A6)

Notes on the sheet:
DSI Connector
CSI Connector
MIPI (CSI/DCI) Connector

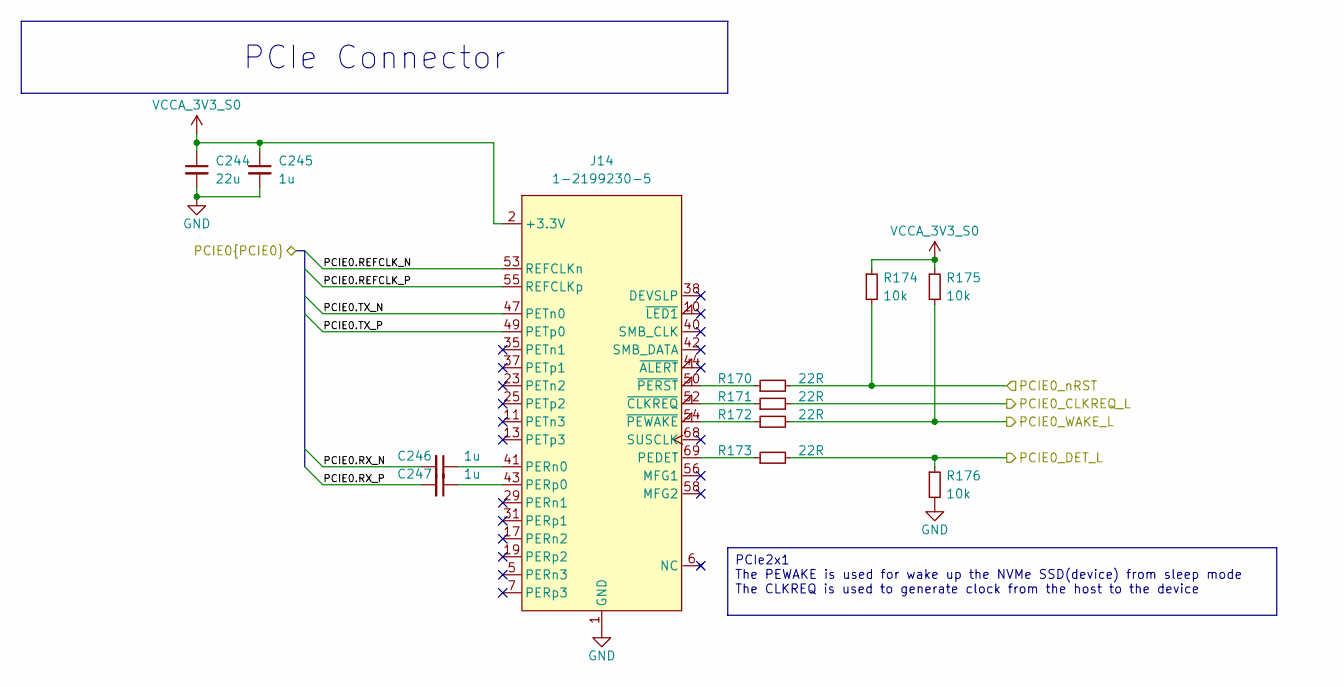
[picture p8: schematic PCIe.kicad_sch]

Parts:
C244: 22u; C_0603_1608Metric; Mouser Part CL10A226MP8NUNE; LCSC Part C86295
C245, C246, C247: 1u; C_0201_0603Metric_Pad0.64x0.40mm_HandSolder; Mouser Part CL03A105KP3NSNC; LCSC Part C5209398
J14: 1-2199230-5; PCIE-SMD_75P-P0.50_1-2199230-5; MPN 1-2199230-5; LCSC Part C590854
R170, R171, R172, R173: 22R; R_0402_1005Metric; Mouser Part 603-RC0402FR-070RL; LCSC Part C106231
R174, R175, R176: 10k; R_0402_1005Metric; Mouser Part 603-RC0402FR-0710KL; LCSC Part C60490

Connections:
/PCIe/PCIE0.REFCLK_N: J14.53 (REFCLKn); also elsewhere on the board
/PCIe/PCIE0.REFCLK_P: J14.55 (REFCLKp); also elsewhere on the board
/PCIe/PCIE0.RX_N: C246.2; also elsewhere on the board
/PCIe/PCIE0.RX_P: C247.2; also elsewhere on the board
/PCIe/PCIE0.TX_N: J14.47 (PETn0); also elsewhere on the board
/PCIe/PCIE0.TX_P: J14.49 (PETp0); also elsewhere on the board
/PCIe/PCIE0_CLKREQ_L: R171.2; also elsewhere on the board
/PCIe/PCIE0_DET_L: R173.2, R176.1; also elsewhere on the board
/PCIe/PCIE0_WAKE_L: R172.2, R175.2; also elsewhere on the board
/PCIe/PCIE0_nRST: R170.2, R174.2; also elsewhere on the board
unnamed: J14.69 (PEDET), R173.1
unnamed: C246.1, J14.41 (PERn0)
unnamed: C247.1, J14.43 (PERp0)
unnamed: J14.52 (~CLKREQ), R171.1
unnamed: J14.50 (~PERST), R170.1
unnamed: J14.54 (~PEWAKE), R172.1

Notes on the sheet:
PCIe2x1 The PEWAKE is used for wake up the NVMe SSD(device) from sleep mode The CLKREQ is used to generate clock from the host to the device
PCIe Connector

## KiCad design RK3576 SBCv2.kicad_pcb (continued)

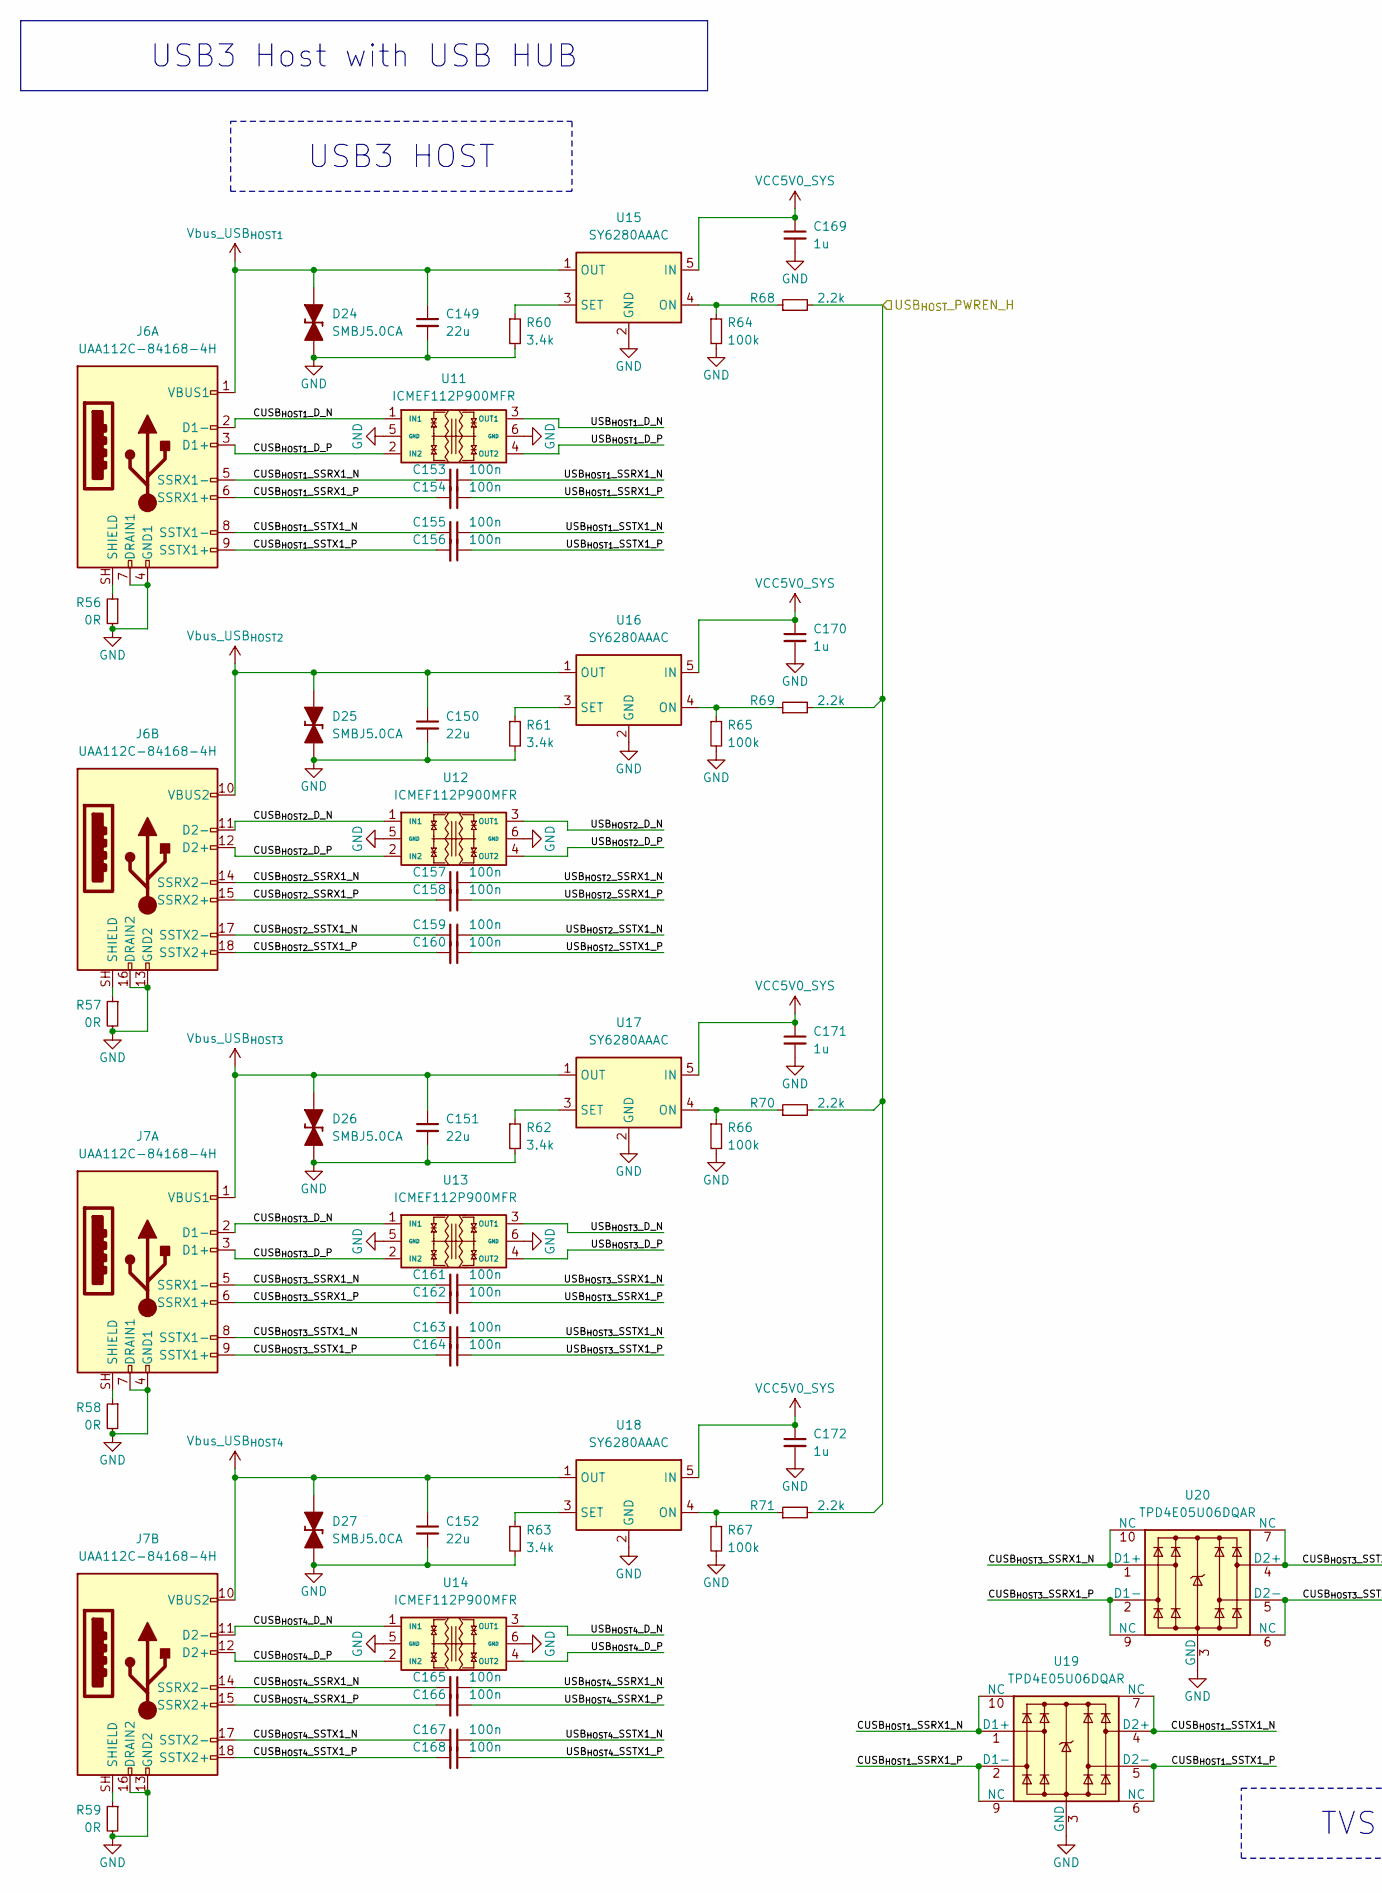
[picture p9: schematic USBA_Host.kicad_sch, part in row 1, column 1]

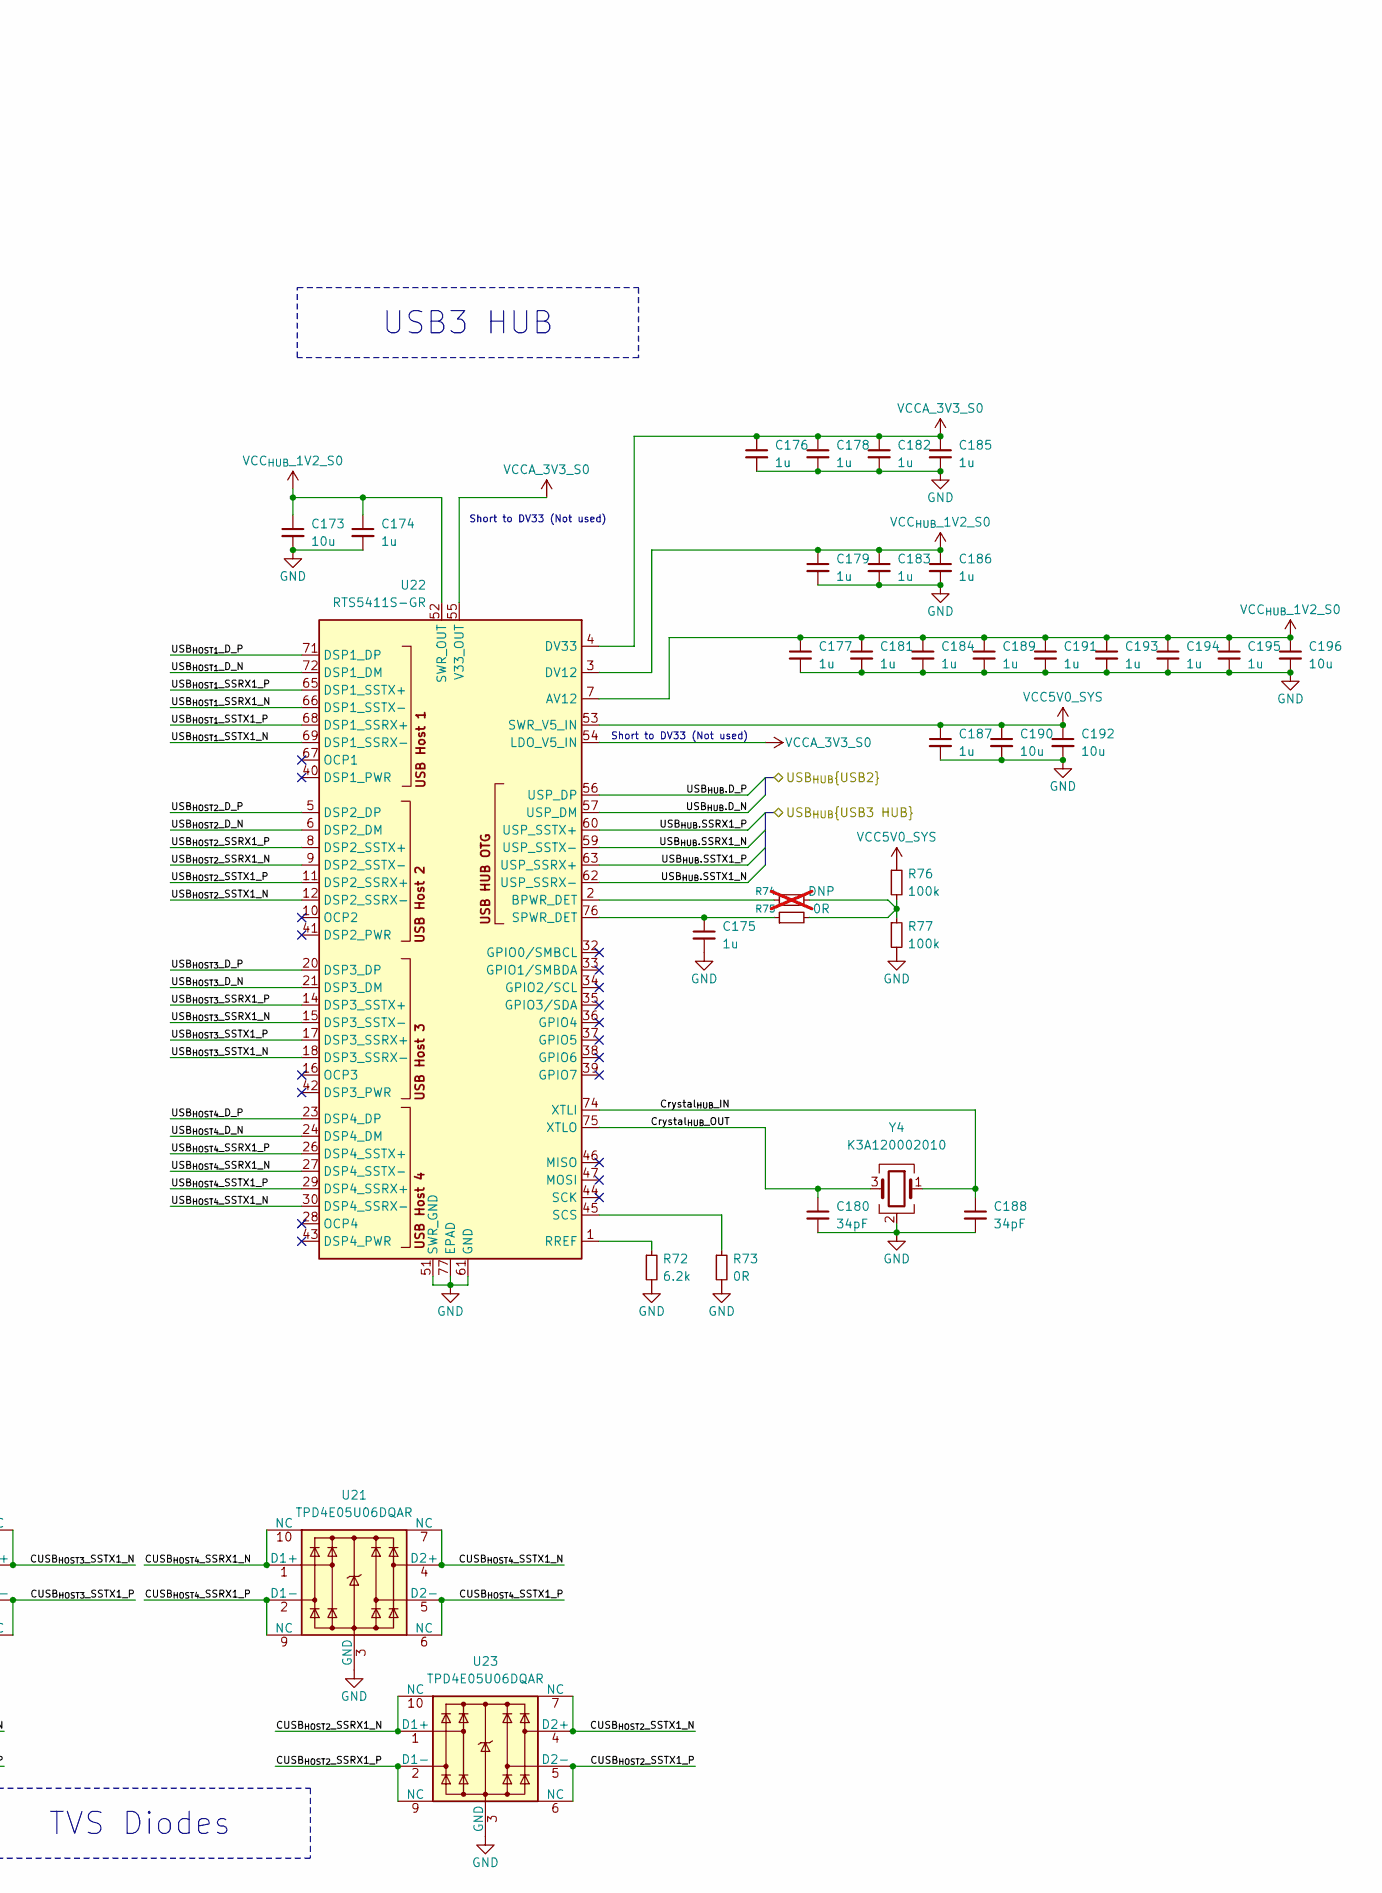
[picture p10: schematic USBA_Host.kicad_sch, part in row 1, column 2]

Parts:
C149, C150, C151, C152: 22u; C_0603_1608Metric; Mouser Part CL10A226MP8NUNE; LCSC Part C86295
C153, C154, C155, C156, C157, C158, C159, C160: 100n; C_0201_0603Metric_Pad0.64x0.40mm_HandSolder; Mouser Part 187-CL03A104KO3NNNC; LCSC Part C307380
C161, C162, C163, C164, C165, C166, C167, C168: 100n; C_0201_0603Metric_Pad0.64x0.40mm_HandSolder; Mouser Part 187-CL03A104KO3NNND; LCSC Part C307380
C169, C170, C171, C172, C174, C175, C176, C177, C178, C179, C181, C182, C183, C184, C185, C186, C187, C189, C191, C193, C194, C195: 1u; C_0201_0603Metric_Pad0.64x0.40mm_HandSolder; Mouser Part CL03A105KP3NSNC; LCSC Part C5209398
C173, C190, C192, C196: 10u; C_0603_1608Metric; Mouser Part 187-CL10A106KP8NNNC; LCSC Part C19702
C180, C188: 34pF; C_0402_1005Metric; Mouser Part CC402JRNPO9BN360; LCSC Part C114394
D24, D25, D26, D27: SMBJ5.0CA; D_SMB_TVS; Mouser Part 581-SMBJ5.0CA; LCSC Part C113975
J6, J7: UAA112C-84168-4H; USB3_A_Molex_48406-0001_Horizontal_Stacked; LCSC Part C42403016
R56, R57, R58, R59, R73, R75: 0R; R_0402_1005Metric; Mouser Part 603-RC0402FR-070RL; LCSC Part C106231
R60, R61, R62, R63: 3.4k; R_0402_1005Metric; Mouser Part 603-RC0402FR-0715KL; LCSC Part C114761
R64, R65, R66, R67, R76, R77: 100k; R_0402_1005Metric; Mouser Part 603-RC0402FR-0710KL; LCSC Part C60490
R68, R69, R70, R71: 2.2k; R_0402_1005Metric; Mouser Part 603-RC0402FR-072K2L; LCSC Part C114762
R72: 6.2k; R_0402_1005Metric; Mouser Part 603-RT0402FRE076K2L; LCSC Part C854413
R74: DNP; R_0402_1005Metric; Mouser Part 603-RC0402FR-070RL; LCSC Part C106231; not fitted
U11, U12, U13, U14: ICMEF112P900MFR; LCSC Part C125058
U15, U16, U17, U18: SY6280AAAC; SOT-23-5; LCSC Part C207620
U19, U20, U21, U23: TPD4E05U06DQAR; USON-10_2.5x1.0mm_P0.5mm; Mouser Part 595-TPD4E05U06DQAR; LCSC Part C138714
U22: RTS5411S-GR; QFN-76-1EP_9x9mm_P0.4mm_EP5.81x6.31mm_ThermalVias; LCSC Part C5356838
Y4: K3A120002010; Crystal_SMD_3225-4Pin_3.2x2.5mm_HandSoldering; LCSC Part C368730

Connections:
/RK3576 SOC/USB_{HOST}_PWREN_H: R68.2, R69.2, R70.2, R71.2; also elsewhere on the board
/RK3576 SOC/USB_{HUB}.D_N: U22.57 (USP_DM); also elsewhere on the board
/RK3576 SOC/USB_{HUB}.D_P: U22.56 (USP_DP); also elsewhere on the board
/USB-A Host/CUSB_{HOST1}_D_N: J6.2 (D1-), U11.1 (IN1)
/USB-A Host/CUSB_{HOST1}_D_P: J6.3 (D1+), U11.2 (IN2)
/USB-A Host/CUSB_{HOST1}_SSRX1_N: C153.2, J6.5 (SSRX1-), U19.1 (D1+), U19.10 (NC)
/USB-A Host/CUSB_{HOST1}_SSRX1_P: C154.2, J6.6 (SSRX1+), U19.2 (D1-), U19.9 (NC)
/USB-A Host/CUSB_{HOST1}_SSTX1_N: C155.2, J6.8 (SSTX1-), U19.4 (D2+), U19.7 (NC)
/USB-A Host/CUSB_{HOST1}_SSTX1_P: C156.2, J6.9 (SSTX1+), U19.5 (D2-), U19.6 (NC)
/USB-A Host/CUSB_{HOST2}_D_N: J6.11 (D2-), U12.1 (IN1)
/USB-A Host/CUSB_{HOST2}_D_P: J6.12 (D2+), U12.2 (IN2)
/USB-A Host/CUSB_{HOST2}_SSRX1_N: C157.2, J6.14 (SSRX2-), U23.1 (D1+), U23.10 (NC)
/USB-A Host/CUSB_{HOST2}_SSRX1_P: C158.2, J6.15 (SSRX2+), U23.2 (D1-), U23.9 (NC)
/USB-A Host/CUSB_{HOST2}_SSTX1_N: C159.2, J6.17 (SSTX2-), U23.4 (D2+), U23.7 (NC)
/USB-A Host/CUSB_{HOST2}_SSTX1_P: C160.2, J6.18 (SSTX2+), U23.5 (D2-), U23.6 (NC)
/USB-A Host/CUSB_{HOST3}_D_N: J7.2 (D1-), U13.1 (IN1)
/USB-A Host/CUSB_{HOST3}_D_P: J7.3 (D1+), U13.2 (IN2)
/USB-A Host/CUSB_{HOST3}_SSRX1_N: C161.2, J7.5 (SSRX1-), U20.1 (D1+), U20.10 (NC)
/USB-A Host/CUSB_{HOST3}_SSRX1_P: C162.2, J7.6 (SSRX1+), U20.2 (D1-), U20.9 (NC)
/USB-A Host/CUSB_{HOST3}_SSTX1_N: C163.2, J7.8 (SSTX1-), U20.4 (D2+), U20.7 (NC)
/USB-A Host/CUSB_{HOST3}_SSTX1_P: C164.2, J7.9 (SSTX1+), U20.5 (D2-), U20.6 (NC)
/USB-A Host/CUSB_{HOST4}_D_N: J7.11 (D2-), U14.1 (IN1)
/USB-A Host/CUSB_{HOST4}_D_P: J7.12 (D2+), U14.2 (IN2)
/USB-A Host/CUSB_{HOST4}_SSRX1_N: C165.2, J7.14 (SSRX2-), U21.1 (D1+), U21.10 (NC)
/USB-A Host/CUSB_{HOST4}_SSRX1_P: C166.2, J7.15 (SSRX2+), U21.2 (D1-), U21.9 (NC)
/USB-A Host/CUSB_{HOST4}_SSTX1_N: C167.2, J7.17 (SSTX2-), U21.4 (D2+), U21.7 (NC)
/USB-A Host/CUSB_{HOST4}_SSTX1_P: C168.2, J7.18 (SSTX2+), U21.5 (D2-), U21.6 (NC)
/USB-A Host/Crystal_{HUB}_IN: C188.1, U22.74 (XTLI), Y4.1
/USB-A Host/Crystal_{HUB}_OUT: C180.1, U22.75 (XTLO), Y4.3
/USB-A Host/USB_{HOST1}_D_N: U11.3 (OUT1), U22.72 (DSP1_DM)
/USB-A Host/USB_{HOST1}_D_P: U11.4 (OUT2), U22.71 (DSP1_DP)
/USB-A Host/USB_{HOST1}_SSRX1_N: C153.1, U22.66 (DSP1_SSTX-)
/USB-A Host/USB_{HOST1}_SSRX1_P: C154.1, U22.65 (DSP1_SSTX+)
/USB-A Host/USB_{HOST1}_SSTX1_N: C155.1, U22.69 (DSP1_SSRX-)
/USB-A Host/USB_{HOST1}_SSTX1_P: C156.1, U22.68 (DSP1_SSRX+)
/USB-A Host/USB_{HOST2}_D_N: U12.3 (OUT1), U22.6 (DSP2_DM)
/USB-A Host/USB_{HOST2}_D_P: U12.4 (OUT2), U22.5 (DSP2_DP)
/USB-A Host/USB_{HOST2}_SSRX1_N: C157.1, U22.9 (DSP2_SSTX-)
/USB-A Host/USB_{HOST2}_SSRX1_P: C158.1, U22.8 (DSP2_SSTX+)
/USB-A Host/USB_{HOST2}_SSTX1_N: C159.1, U22.12 (DSP2_SSRX-)
/USB-A Host/USB_{HOST2}_SSTX1_P: C160.1, U22.11 (DSP2_SSRX+)
/USB-A Host/USB_{HOST3}_D_N: U13.3 (OUT1), U22.21 (DSP3_DM)
/USB-A Host/USB_{HOST3}_D_P: U13.4 (OUT2), U22.20 (DSP3_DP)
/USB-A Host/USB_{HOST3}_SSRX1_N: C161.1, U22.15 (DSP3_SSTX-)
/USB-A Host/USB_{HOST3}_SSRX1_P: C162.1, U22.14 (DSP3_SSTX+)
/USB-A Host/USB_{HOST3}_SSTX1_N: C163.1, U22.18 (DSP3_SSRX-)
/USB-A Host/USB_{HOST3}_SSTX1_P: C164.1, U22.17 (DSP3_SSRX+)
/USB-A Host/USB_{HOST4}_D_N: U14.3 (OUT1), U22.24 (DSP4_DM)
/USB-A Host/USB_{HOST4}_D_P: U14.4 (OUT2), U22.23 (DSP4_DP)
/USB-A Host/USB_{HOST4}_SSRX1_N: C165.1, U22.27 (DSP4_SSTX-)
/USB-A Host/USB_{HOST4}_SSRX1_P: C166.1, U22.26 (DSP4_SSTX+)
/USB-A Host/USB_{HOST4}_SSTX1_N: C167.1, U22.30 (DSP4_SSRX-)
/USB-A Host/USB_{HOST4}_SSTX1_P: C168.1, U22.29 (DSP4_SSRX+)
/USB-A Host/USB_{HUB}.SSRX1_N: U22.59 (USP_SSTX-)
/USB-A Host/USB_{HUB}.SSRX1_P: U22.60 (USP_SSTX+)
/USB-A Host/USB_{HUB}.SSTX1_N: U22.62 (USP_SSRX-)
/USB-A Host/USB_{HUB}.SSTX1_P: U22.63 (USP_SSRX+)
unnamed: R74.2, R75.2, R76.2, R77.1
unnamed: R64.1, R68.1, U15.4 (ON)
unnamed: R60.1, U15.3 (SET)
unnamed: R65.1, R69.1, U16.4 (ON)
unnamed: R61.1, U16.3 (SET)
unnamed: R66.1, R70.1, U17.4 (ON)
unnamed: R62.1, U17.3 (SET)
unnamed: R67.1, R71.1, U18.4 (ON)
unnamed: R63.1, U18.3 (SET)
unnamed: R74.1, U22.2 (BPWR_DET)
unnamed: R72.1, U22.1 (RREF)
unnamed: R73.1, U22.45 (SCS)
unnamed: C175.1, R75.1, U22.76 (SPWR_DET)
VCC_{HUB}_1V2_S0: C173.1, C174.1, C177.1, C179.1, C181.1, C183.1, C184.1, C186.1, C189.1, C191.1, C193.1, C194.1, C195.1, C196.1, U22.3 (DV12), U22.7 (AV12), U22.13 (AV12), U22.19 (AV12), U22.25 (AV12), U22.31 (AV12), U22.49 (DV12), U22.50 (DV12), U22.52 (SWR_OUT), U22.58 (AV12), U22.64 (AV12), U22.70 (AV12)
Vbus_USB_{HOST1}: C149.1, D24.2 (A), J6.1 (VBUS1), U15.1 (OUT)
Vbus_USB_{HOST2}: C150.1, D25.2 (A), J6.10 (VBUS2), U16.1 (OUT)
Vbus_USB_{HOST3}: C151.1, D26.2 (A), J7.1 (VBUS1), U17.1 (OUT)
Vbus_USB_{HOST4}: C152.1, D27.2 (A), J7.10 (VBUS2), U18.1 (OUT)

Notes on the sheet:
Short to DV33 (Not used)
USB3 HUB
USB3 Host with USB HUB
TVS Diodes
USB3 HOST

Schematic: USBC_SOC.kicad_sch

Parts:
C131, C132, C133, C134, C135, C136, C137, C138, C139, C140: 100n; C_0201_0603Metric_Pad0.64x0.40mm_HandSolder; Mouser Part 187-CL03A104KO3NNNC; LCSC Part C307380
C141: 22u; C_0603_1608Metric; Mouser Part CL10A226MP8NUNE; LCSC Part C86295
C142: DNP; C_0201_0603Metric_Pad0.64x0.40mm_HandSolder; not fitted
C143, C144: 200pF; C_0402_1005Metric; Mouser Part 603-CC402JRNPO9BN201; LCSC Part C325462
C145, C146, C147, C148: 1u; C_0201_0603Metric_Pad0.64x0.40mm_HandSolder; Mouser Part CL03A105KP3NSNC; LCSC Part C5209398
D21: SMBJ5.0CA; D_SMB_TVS; Mouser Part 581-SMBJ5.0CA; LCSC Part C113975
D22, D23: PESD5V0S1BA; D_SOD-323_TVS; Mouser Part 771-PESD5V0S1BA-T/R; LCSC Part C5158048
J5: USB_C_Receptacle; USB-C-SMD_GT-USB-7092B; LCSC Part C22471967
R47: 0R; R_0402_1005Metric; Mouser Part 603-RC0402FR-070RL; LCSC Part C106231
R48, R49: 2M; R_0402_1005Metric; Mouser Part 603-RC0402FR-0710KL; LCSC Part C60490
R50, R51: 100k; R_0402_1005Metric; Mouser Part 603-RC0402FR-0710KL; LCSC Part C60490
R52, R53, R54: 10k; R_0402_1005Metric; Mouser Part 603-RC0402FR-0710KL; LCSC Part C60490
R55: 22R; R_0402_1005Metric; Mouser Part 603-RC0402FR-070RL; LCSC Part C106231
U5: ICMEF112P900MFR; LCSC Part C125058
U6: TPS22953DQCR; WSON-10-2x3-EP_TPS22953DQCR; LCSC Part C471046
U7: FUSB302BMPX; WQFN-14-1EP_2.5x2.5mm_P0.5mm_EP1.45x1.45mm; Mouser Part 512-FUSB302BMPX; LCSC Part C132291
U8, U9, U10: TPD4E05U06DQAR; USON-10_2.5x1.0mm_P0.5mm; Mouser Part 595-TPD4E05U06DQAR

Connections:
/RK3576 SOC/I2C2_SCL_M0_USB_Wireless: U7.6 (SCL); also elsewhere on the board
/RK3576 SOC/I2C2_SDA_M0_USB_Wireless: U7.7 (SDA); also elsewhere on the board
/RK3576 SOC/USB_{SOC}.D_N: U5.3 (OUT1); also elsewhere on the board
/RK3576 SOC/USB_{SOC}.D_P: U5.4 (OUT2); also elsewhere on the board
/RK3576 SOC/USB_{SOC}.PUPDCTRL1: R50.2; also elsewhere on the board
/RK3576 SOC/USB_{SOC}.PUPDCTRL2: R51.2; also elsewhere on the board
/RK3576 SOC/USB_{SOC}_CON_INT: U7.5 (INT_N); also elsewhere on the board
/RK3576 SOC/USB_{SOC}_PWREN_H: R55.2; also elsewhere on the board
/RK3576 SOC/Vdet_USB_{SOC}: R52.2, R53.1; also elsewhere on the board
/USB-C SOC/CUSB_{SOC}_AUX_N: C140.2, J5.B8 (SBU2), R49.1, R51.1, U10.5 (D2-), U10.6 (NC)
/USB-C SOC/CUSB_{SOC}_AUX_P: C139.2, J5.A8 (SBU1), R48.1, R50.1, U10.4 (D2+), U10.7 (NC)
/USB-C SOC/CUSB_{SOC}_D_N: J5.A7 (D-), J5.B7 (D-), U5.1 (IN1), U8.1 (D1+), U8.10 (NC)
/USB-C SOC/CUSB_{SOC}_D_P: J5.A6 (D+), J5.B6 (D+), U5.2 (IN2), U8.2 (D1-), U8.9 (NC)
/USB-C SOC/CUSB_{SOC}_RX1_N: C131.2, J5.B10 (RX1-), U8.4 (D2+), U8.7 (NC)
/USB-C SOC/CUSB_{SOC}_RX1_P: C132.2, J5.B11 (RX1+), U8.5 (D2-), U8.6 (NC)
/USB-C SOC/CUSB_{SOC}_RX2_N: C135.2, J5.A10 (RX2-), U9.4 (D2+), U9.7 (NC)
/USB-C SOC/CUSB_{SOC}_RX2_P: C136.2, J5.A11 (RX2+), U9.5 (D2-), U9.6 (NC)
/USB-C SOC/CUSB_{SOC}_TX1_N: C133.2, J5.A3 (TX1-), U9.1 (D1+), U9.10 (NC)
/USB-C SOC/CUSB_{SOC}_TX1_P: C134.2, J5.A2 (TX1+), U9.2 (D1-), U9.9 (NC)
/USB-C SOC/CUSB_{SOC}_TX2_N: C137.2, J5.B3 (TX2-), U10.1 (D1+), U10.10 (NC)
/USB-C SOC/CUSB_{SOC}_TX2_P: C138.2, J5.B2 (TX2+), U10.2 (D1-), U10.9 (NC)
/USB-C SOC/USB_{SOC}.AUX_N: C140.1
/USB-C SOC/USB_{SOC}.AUX_P: C139.1
/USB-C SOC/USB_{SOC}.RX1_N: C131.1
/USB-C SOC/USB_{SOC}.RX1_P: C132.1
/USB-C SOC/USB_{SOC}.RX2_N: C135.1
/USB-C SOC/USB_{SOC}.RX2_P: C136.1
/USB-C SOC/USB_{SOC}.TX1_N: C133.1
/USB-C SOC/USB_{SOC}.TX1_P: C134.1
/USB-C SOC/USB_{SOC}.TX2_N: C137.1
/USB-C SOC/USB_{SOC}.TX2_P: C138.1
/USB-C SOC/USB_{SOC}_CC1: C143.1, D22.2 (A), J5.A5 (CC1), U7.10 (CC1), U7.11 (CC1)
/USB-C SOC/USB_{SOC}_CC2: C144.1, D23.2 (A), J5.B5 (CC2), U7.1 (CC2), U7.14 (CC2)
unnamed: J5.SH (SHIELD), R47.1
unnamed: C142.1, U6.6 (CT)
unnamed: R54.1, R55.1, U6.4 (EN)
Vbus_USB_{OTG}: C141.1, D21.2 (A), J5.A4 (VBUS), J5.A9 (VBUS), J5.B4 (VBUS), J5.B9 (VBUS), R52.1, U6.8 (SNS), U6.9 (OUT), U6.10 (OUT), U7.2 (VBUS)

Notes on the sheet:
Need rating 25v or higher
USB3.2 OTG With Controller
TVS Diodes
USB_{SOC} Power EN

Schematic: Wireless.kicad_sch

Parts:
C248, C249, C250: 1u; C_0201_0603Metric_Pad0.64x0.40mm_HandSolder; Mouser Part CL03A105KP3NSNC; LCSC Part C5209398
C251: 22u; C_0603_1608Metric; Mouser Part CL10A226MP8NUNE; LCSC Part C86295
J15: APCI0108-P001A; MPN APCI0108-P001A; LCSC Part C7498141
R177, R178, R179, R180, R181, R182: 22R; R_0402_1005Metric; Mouser Part 603-RC0402FR-070RL; LCSC Part C106231
R183: 10k; R_0402_1005Metric; Mouser Part 603-RC0402FR-0710KL; LCSC Part C60490; not fitted
R184, R185: 2.2k; R_0402_1005Metric; Mouser Part 603-RC0402FR-072K2L; LCSC Part C114762

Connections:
/RK3576 SOC/BT_REG_ON_L: J15.54 (~BT_REG_ON); also elsewhere on the board
/RK3576 SOC/BT_WAKE_DEV_L: J15.42 (~BT_DEV_WAKE_L); also elsewhere on the board
/RK3576 SOC/BT_WAKE_HOST_L: J15.20 (~BT_HOST_WAKE_L); also elsewhere on the board
/RK3576 SOC/I2C2_SCL_M0_USB_Wireless: J15.60 (I2C_SCL), R185.2; also elsewhere on the board
/RK3576 SOC/I2C2_SDA_M0_USB_Wireless: J15.58 (I2C_SDA), R184.2; also elsewhere on the board
/RK3576 SOC/SDMMC1.CLK_M0: R181.1; also elsewhere on the board
/RK3576 SOC/SDMMC1.CMD_M0: R182.1; also elsewhere on the board
/RK3576 SOC/WIFI_REG_ON_L: J15.56 (~WLAN_REG_ON); also elsewhere on the board
/RK3576 SOC/WIFI_WAKE_DEV_L: J15.40 (~WLAN_DEV_WAKE_L); also elsewhere on the board
/RK3576 SOC/WIFI_WAKE_HOST_L: J15.21 (~WLAN_HOST_WAKE_L); also elsewhere on the board
/RK3576 SOC/WIFI_nRST: J15.23 (~WLAN_RESET_N); also elsewhere on the board
/RK3576 SOC/WIRELESS_ALERT_L: J15.62 (~ALERT_N), R183.2; also elsewhere on the board
/RTC/RTC_32KOUT_WIFI: J15.50 (SUSCLK_32K); also elsewhere on the board
/Wireless/SAI2.LRCK_M0: J15.10 (BT_PCM_SYNC)
/Wireless/SAI2.SCLK_M0: J15.8 (BT_PCM_CLK)
/Wireless/SAI2.SDI_M0: J15.12 (BT_PCM_OUT)
/Wireless/SAI2.SDO_M0: J15.14 (BT_PCM_IN)
/Wireless/SDMMC1.CLK: J15.9 (WLAN_SDIO_CLK), R181.2
/Wireless/SDMMC1.CMD: J15.11 (WLAN_SDIO_CMD), R182.2
/Wireless/SDMMC1.D0: J15.13 (WLAN_SDIO_D0), R177.2
/Wireless/SDMMC1.D0_M0: R177.1
/Wireless/SDMMC1.D1: J15.15 (WLAN_SDIO_D1), R178.2
/Wireless/SDMMC1.D1_M0: R178.1
/Wireless/SDMMC1.D2: J15.17 (WLAN_SDIO_D2), R179.2
/Wireless/SDMMC1.D2_M0: R179.1
/Wireless/SDMMC1.D3: J15.19 (WLAN_SDIO_D3), R180.2
/Wireless/SDMMC1.D3_M0: R180.1
/Wireless/UART4.CTSN_M1: J15.34 (BT_UART_RTS)
/Wireless/UART4.RTSN_M1: J15.36 (BT_UART_CTS)
/Wireless/UART4.RX_M1: J15.22 (BT_UART_TXD)
/Wireless/UART4.TX_M1: J15.32 (BT_UART_RXD)

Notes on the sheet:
OUR Connect Support SDIO for WIFI and UART&PCM for Blutooth So Modules use PCIe and USB are not support
Wireless Module & Antennas
ALERT pin i used for wake up the Host SUSCLK is 32.768k Hz CLK IN the M.2 for the modules don't have it internal This pins Not used in alot of modules thats why we don't need it.

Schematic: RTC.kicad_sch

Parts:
BT1: BS-06-B4AA012; BAT-SMD_BS-06-B4AA012; LCSC Part C964758
C340, C341, C342: 1u; C_0201_0603Metric_Pad0.64x0.40mm_HandSolder; Mouser Part CL03A105KP3NSNC; LCSC Part C5209398
D59: SMBJ5.0CA; D_SMB_TVS; Mouser Part 581-SMBJ5.0CA; LCSC Part C113975
F1: 1812L010/100GR; Fuse_1812_4532Metric; LCSC Part C28326708
Q6: AO3401A; SOT-23; LCSC Part C347476
R200, R201: 2.2k; R_0402_1005Metric; Mouser Part 603-RC0402FR-072K2L; LCSC Part C114762
R202, R203: 10k; R_0402_1005Metric; Mouser Part 603-RC0402FR-0710KL; LCSC Part C60490
R204, R205: 22R; R_0402_1005Metric; Mouser Part 603-RC0402FR-070RL; LCSC Part C106231
U39: M24C64-RMN6TP; SOIC-8_3.9x4.9mm_P1.27mm; Mouser Part 511-M24C64-RMN6TP; LCSC Part C79988
U40: RV-3028-C7; MicroCrystal_C7_SON-8_1.5x3.2mm_P0.9mm; Mouser Part 428-203591-MG01

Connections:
/40pin GPIO/I2C8_SCL_M3_RTC_EEPROM: R200.2, U39.6 (SCL), U40.3 (SCL); also elsewhere on the board
/40pin GPIO/I2C8_SDA_M3_RTC_EEPROM: R201.2, U39.5 (SDA), U40.4 (SDA); also elsewhere on the board
/RK3576 SOC/EEPROM_WP: U39.7 (WP); also elsewhere on the board
/RK3576 SOC/RTC_32KOUT_SOC: R204.2; also elsewhere on the board
/RK3576 SOC/RTC_INT_L: U40.2 (~INT); also elsewhere on the board
/RTC/RTC_32KOUT_WIFI: R205.2; also elsewhere on the board
unnamed: BT1.1 (+), F1.2
unnamed: D59.2 (A), F1.1, Q6.3 (D)
unnamed: Q6.1 (G), R203.1
unnamed: C342.1, Q6.2 (S), U40.6 (VBACKUP)
unnamed: R202.2, R204.1, R205.1, U40.1 (CLKOUT)
VCC_3.3v_S0: C340.1, U39.8 (VDD); also elsewhere on the board

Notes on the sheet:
RTC & Backup BATT
EEPROM
RTC

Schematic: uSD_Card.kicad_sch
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

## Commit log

2026-08-31 V0.1 of schematics
    [40pin_header.kicad_sch, RK3576 SBC.csv, RK3576 SBC.kicad_pcb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]
2026-09-14 SBC Board V0.2
    The SBC schematics before footprint and part number check
    [40pin_header.kicad_sch, RK3576 SBC.kicad_pcb, RK3576 SBC.kicad_sch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]
2026-09-15 SBCv0.3
    there is no big thing update just some LCSC & Mouser parts
    and Big problem deleted alot of component values (:
    [40pin_header.kicad_sch, RK3576 SBC.csv, RK3576 SBC.kicad_pcb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]
2026-09-16 SBCv0.4
    add LCSC & Mouser parts
    and solve the deleted value in the past version
    [40pin_header.kicad_sch, RK3576 SBC.csv, RP2350A.kicad_sch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]
2026-09-17 SBCv0.5
    small update for Josa watch the final version
    [40pin_header.kicad_sch, RK3576 SBC.kicad_sch, RK3576.kicad_sch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]
2026-10-01 Release v2: replace main with RK3576 SBCv2, archive v1 to branch archive/v1
    - main now shows only v2 (RK3576 SBCv2.kicad_pro)
    - v1 preserved in branch archive/v1 + tag v1.0
    - Add .gitignore for KiCad (*.bak, *.lck, .history/)
    - Update README with version switcher
    - Cleaned: dropped 141M .history, Resources ref PDF, *.bak/*.lck
    [40pin_GPIO.kicad_sch, 40pin_header.kicad_sch, Ethernet.kicad_sch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]
2026-10-01 Sync v2: remove eMMC/ and UFS/ folders deleted locally
    [UFS.kicad_sch, eMMC.kicad_sch]
2026-10-01 Replace v2 with correct source: RK3576_SBCv2 (Copy) (2)
    - Delete previous v2 files, upload cleaned (2) version
    - Restore eMMC/ and UFS/ storage sheets
    - Drop connectors, dc_power_soket, digital, fixtures, power placeholders
    - Update RK3576 SBCv2.kicad_pro
    - Exclude: .history (141M), Resources ref PDF, *.bak, *.lck
    [UFS.kicad_sch, connectors.kicad_sch, digital.kicad_sch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]
2026-10-01 Remove eMMC/ and UFS/ folders to match local (2)
    [UFS.kicad_sch, eMMC.kicad_sch]
2026-10-01 Add missing v2 sheets: eMMC/UFS, connectors, digital, dc_power
    [UFS.kicad_sch, connectors.kicad_sch, dc_power_soket.kicad_sch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]
2026-10-01 Remove empty orphan placeholders breaking KiCanvas tree load
    [USBC_MCU.kicad_sch, digital.kicad_sch, eMMC_UFS.kicad_sch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]
2026-10-02 Replace v2 with updated RK3576_SBCv2 (Copy) Oct 2
    - Update 18 sheets to Oct 2 15:37 local versions
    - Keep cleaned layout: exclude .history/, Resources/, *.bak, *.lck,
    project.kicad_dru, .hs_rules.json, lowercase dup placeholders
    (fixtures/power), empty orphans (digital, mechanical, output,
    USBC_MCU, eMMC_UFS)
    - Preserve LICENSE, README.md, .gitignore
    [40pin_GPIO.kicad_sch, Ethernet.kicad_sch, Fixtures.kicad_sch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]
2026-10-05 Relink hierarchical root: 18 sheets into RK3576 SBCv2 top level
    Root was empty (no sheet boxes); all subsheets orphaned.
    Rebuilt A1 top level linking RK3576, LPDDR5, Power, Ethernet,
    HDMI, MIPI, PCIe, USB-A/C, Wireless, RTC, uSD, GPIO, OLED,
    RP2350A, Connectors, Fixtures, DC_Power. block_diagrame kept
    docs-only (unlinked, avoids double-instantiation). Lowercase
    stub duplicates excluded. ERC: 1388 -> 770 violations.
    [40pin_GPIO.kicad_sch, Ethernet.kicad_sch, Fixtures.kicad_sch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]
2026-10-07 Update v2 schematics + PCB: impedance profiles, design rules, sheet fixes
    - pro: copper/track widths, microvias, 40/50 OHM + DIFF 85/90/100 tuning profiles
    - dru/pcb: updated constraints and layout
    - sheets: RK3576, RP2350A, Fixtures, MIPI, PCIe, HDMI, LPDDR5, UFS/eMMC, OLED, block diagram
    [Fixtures.kicad_sch, HDMI.kicad_sch, LPDDR5.kicad_sch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]
2026-10-08 block diagrame with Hierarchical labels and NVMe SSD footprint
    [40pin_GPIO.kicad_sch, Ethernet.kicad_sch, Fixtures.kicad_sch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]

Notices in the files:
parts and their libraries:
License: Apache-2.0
